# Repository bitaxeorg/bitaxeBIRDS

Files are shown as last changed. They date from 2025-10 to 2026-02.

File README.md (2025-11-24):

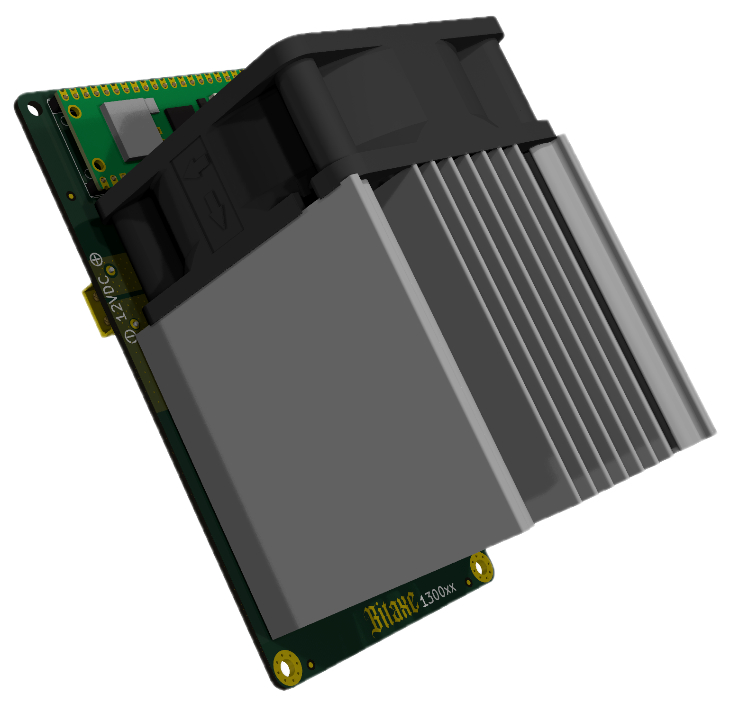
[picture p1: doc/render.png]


Bitaxe Intel Reference Design System (BIRDS) quad Intel BZM2 ASIC miner for BZM2 firmware development.

It is still an untested prototype! Don't build this expecting it to work out of the box. Do build it if you want to hack on some rad stuff.

- Open Hardware License; Real Open Source.
	- [KiCAD](https://kicad.org) design files. 
- Four Intel BZM2 ASICs, powered in series.
	- Each BZM2 is [nominally](doc/specs.md) 0.7V with approx 350 GH/s @ 1.15 GHz hash frequency.
	- On chip digital temperature and voltage sensors
	- ntime rolling
	- decent cross-domain level shifting, that _hopefully_ works. 
- 11-13V XT30 input voltage
- TPS546D24S single-phase voltage regulator tuned for 2.8V output @ 20A
	- The voltage regulator backside power plane is exposed to hopefully thermally bond it with the main heatsink. 
- New fan control strategy (no more EMC2101)
- Controlled by the [RaspberryPi Pico 2W](https://www.raspberrypi.com/products/raspberry-pi-pico-2/) featuring the RP2350 microcontroller and a Infineon CYW43439 WiFi SoC
	- Rumored to have good embedded Rust support
	- Programmable IO controller for integrating with the gnarly 5Mbaud, 9bit serial on the BZM2
    - Preliminary support with the [bitaxe-raw-pico](https://github.com/bitaxeorg/bitaxe-raw/tree/pico) firmware.
    	- Note: this targets the RP2040 in the Pico. It's pin compatible with with RP2350-based Pico 2. 
- Gerbers _not_ provided to discourage side hacks and AliEx slop. HMU if you need help generating gerbers with KiCad.

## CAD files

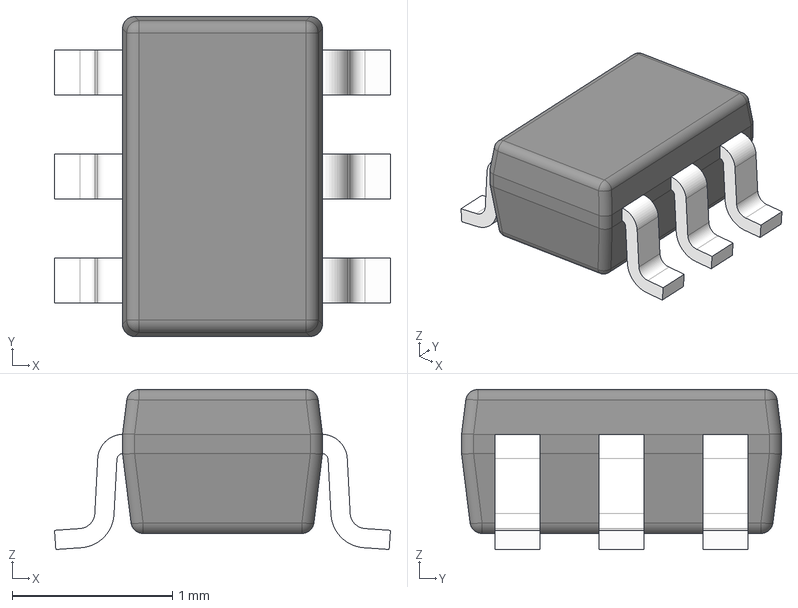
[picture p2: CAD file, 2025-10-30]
3d/DCK0006A.stp
2.10 x 2.00 x 1.00 mm
BODY-SOT
LEAD-SOT x 6
PIN1-ID

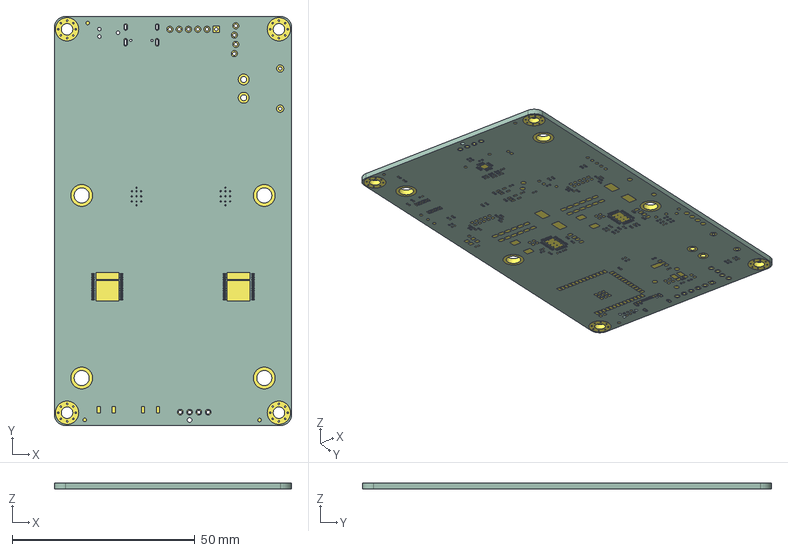
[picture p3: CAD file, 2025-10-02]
bitaxeBIRDS.step
65.0 x 112.0 x 1.59 mm
BitaxeGT_pad
BitaxeGT_PCB

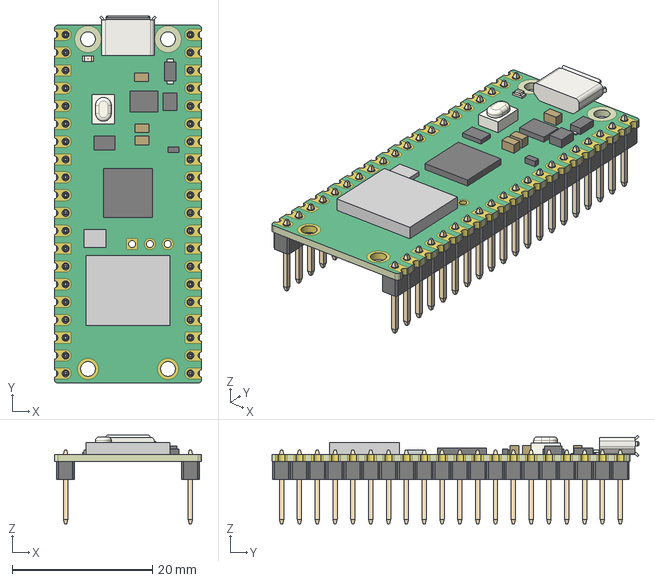
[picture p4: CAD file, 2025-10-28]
3d/RaspberryPi_Pico_W_AddedHeaders.step
21.0 x 52.3 x 12.6 mm

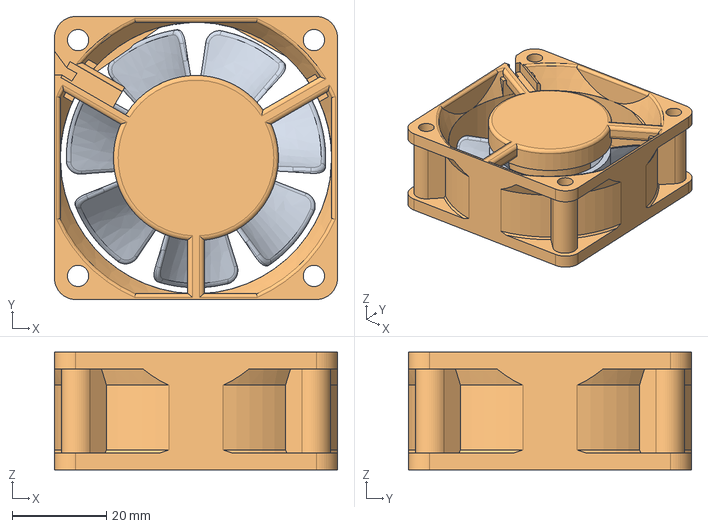
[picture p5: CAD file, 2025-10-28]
3d/Fan 60x60x25mm.stp
60.0 x 60.0 x 25.0 mm

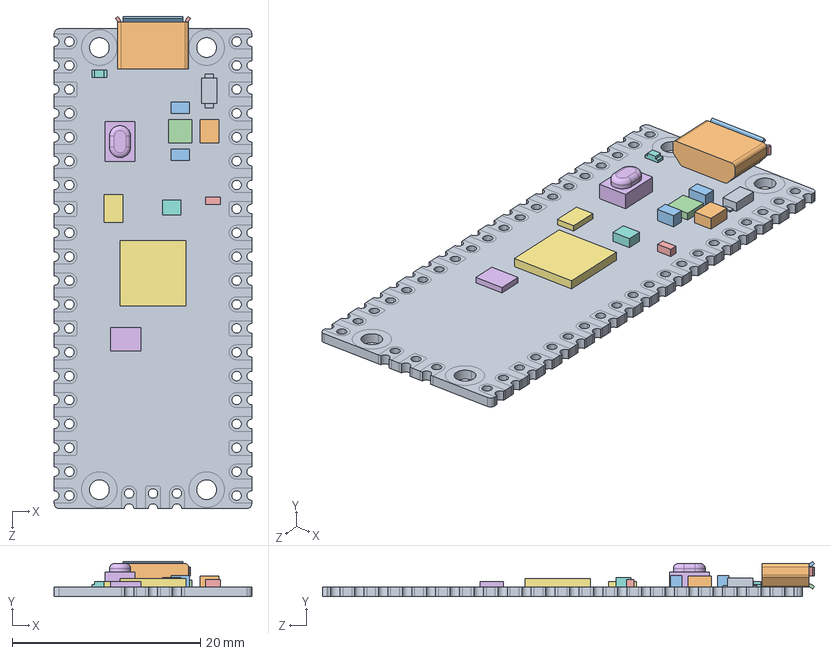
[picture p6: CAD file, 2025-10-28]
3d/RP-006426-DD-A-Raspberry Pi Pico 2 3D CAD Model R5 24 07 24.step
21.0 x 3.73 x 52.3 mm
PICO_REF_BOARD
PICO_REF_USB
PICO_REF_SWITCH
PICO_REF_MICROCONTROLLER
PICO_REF_LED
PICO_REF_COMP_1
PICO_REF_COMP_2
PICO_REF_COMP_3 x 2
PICO_REF_COMP_4
PICO_REF_COMP_5
PICO_REF_COMP_6
PICO_REF_COMP_7
PICO_REF_INDUCTOR

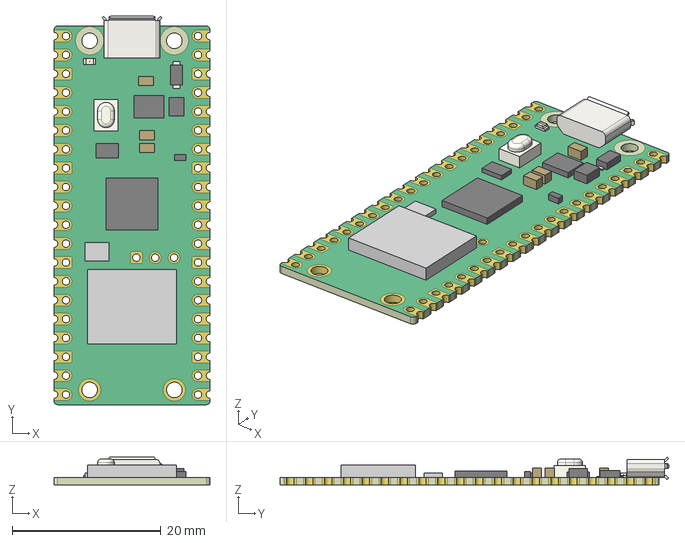
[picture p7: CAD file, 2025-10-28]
3d/RaspberryPi_Pico_W.step
21.0 x 52.3 x 3.75 mm

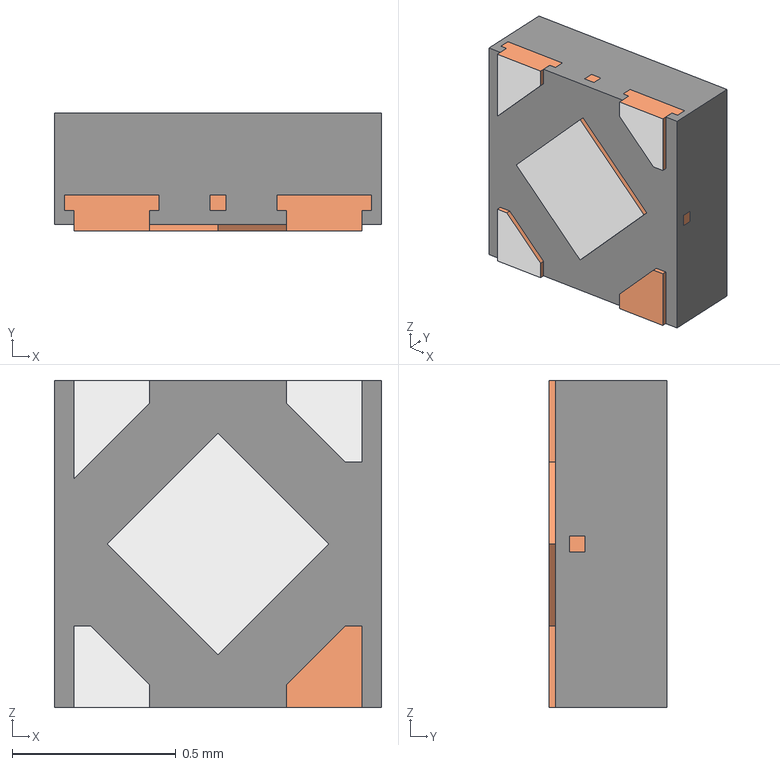
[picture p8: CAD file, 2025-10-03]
3d/DQN0004A.stp
1.00 x 0.36 x 1.00 mm
MOLD-SNB04A
FRAME-SNB04A

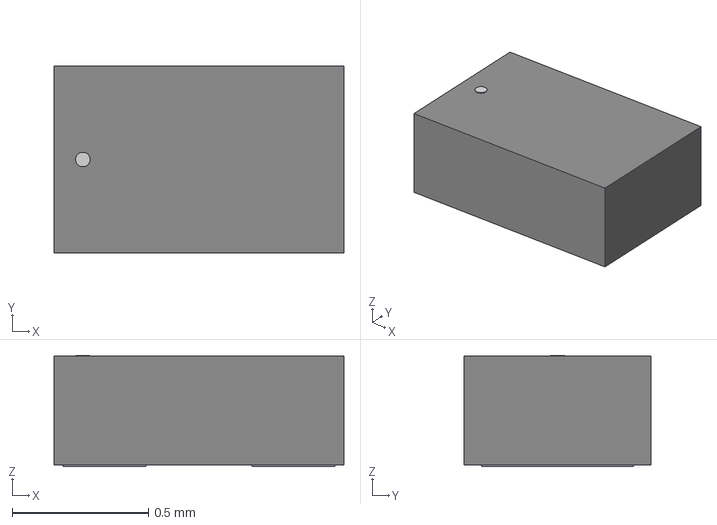
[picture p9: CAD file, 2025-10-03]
3d/DIODE_DLLFSD01LPH4-7B_DIO.step
1.07 x 0.686 x 0.409 mm

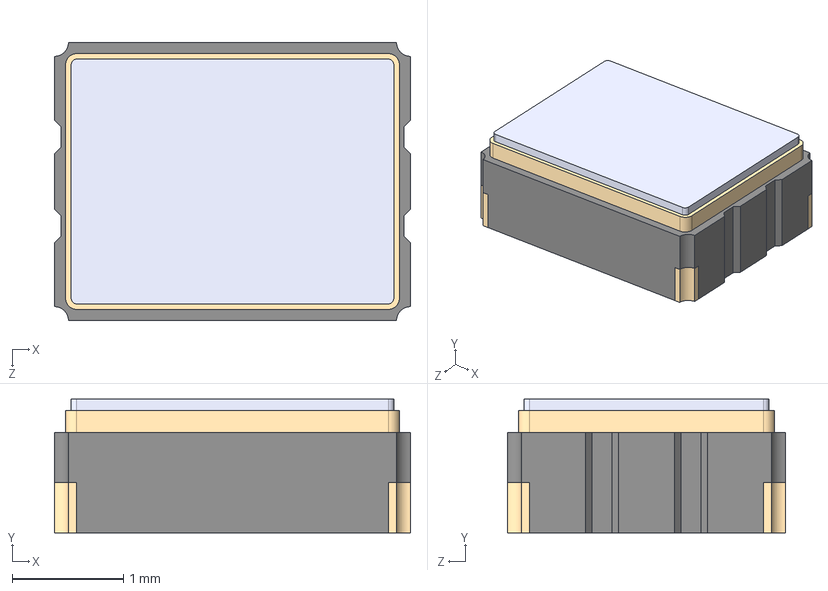
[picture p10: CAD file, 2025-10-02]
3d/ECS-3225MV-500-CN-TR.STEP
3.20 x 1.20 x 2.50 mm

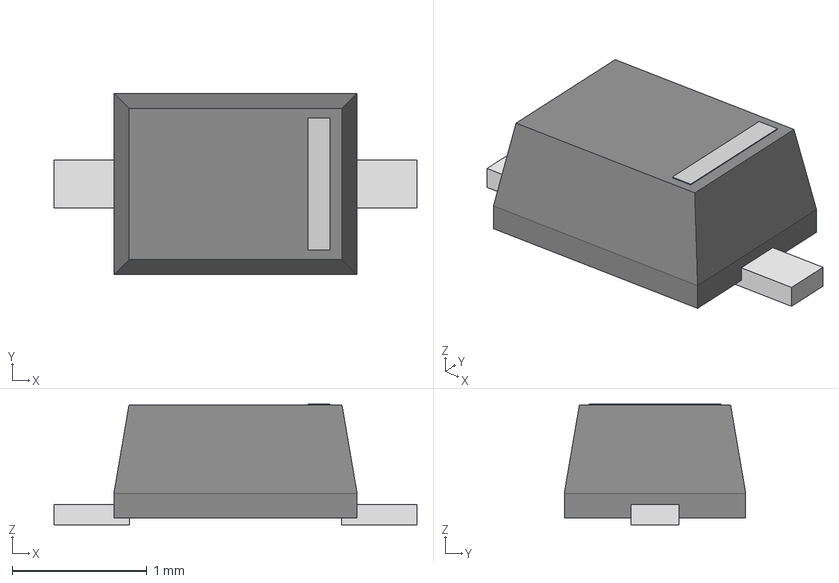
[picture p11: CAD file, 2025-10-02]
3d/SOD-323FL_UMD2__ROM.step
2.69 x 1.35 x 0.895 mm

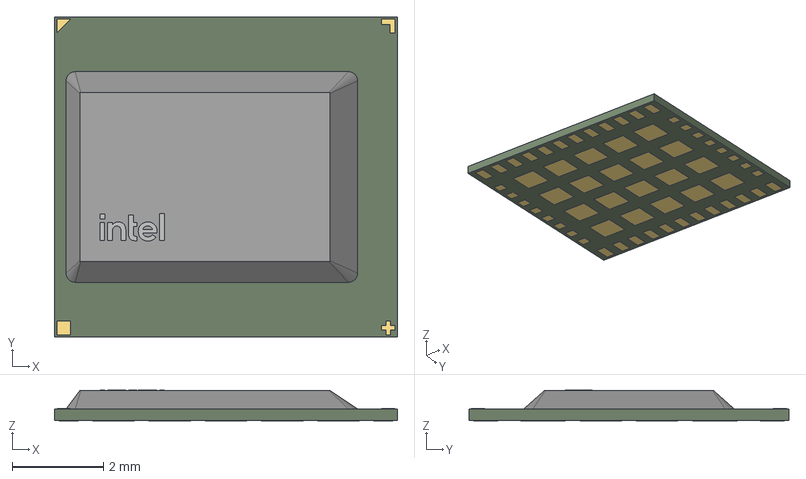
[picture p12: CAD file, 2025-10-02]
3d/BZM2.step
7.50 x 7.00 x 0.669 mm
substrate_part
die_part
underfill_part
intelLogo_part
pin1_part
square_part
plus_part
bracket_part
pads_part

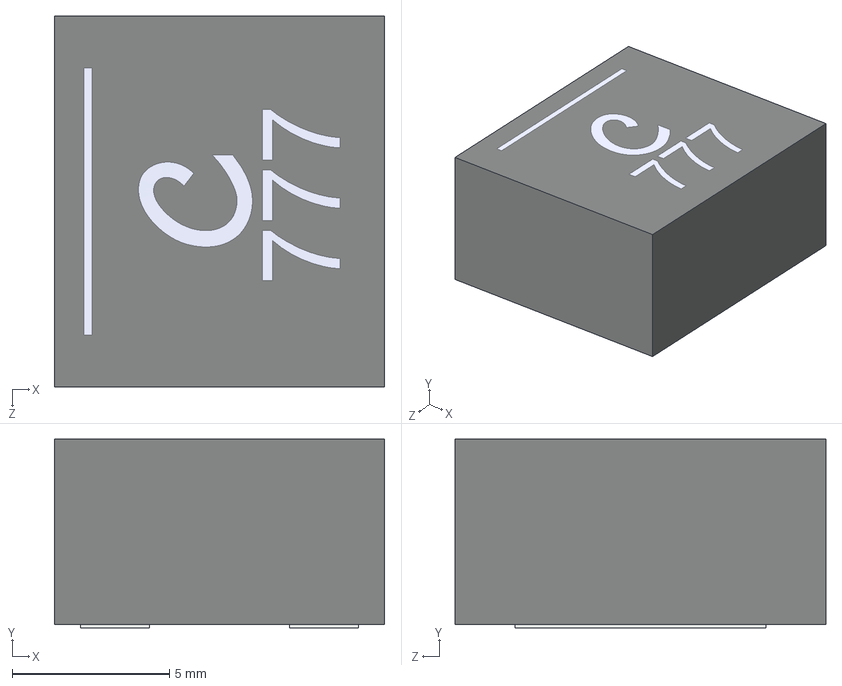
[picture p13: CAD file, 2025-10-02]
3d/Coilcraft-XAL1060.STEP
10.5 x 6.00 x 11.8 mm

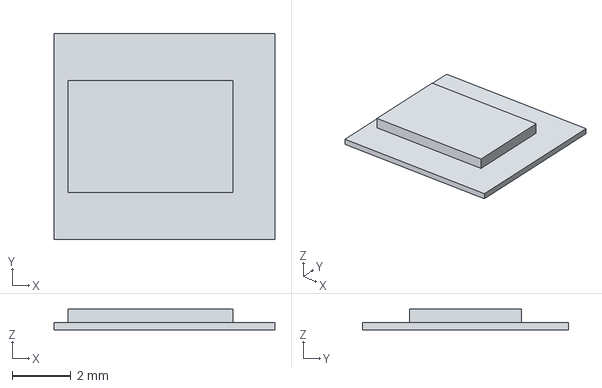
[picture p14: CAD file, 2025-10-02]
3d/BZM2model.step
7.50 x 7.00 x 0.71 mm

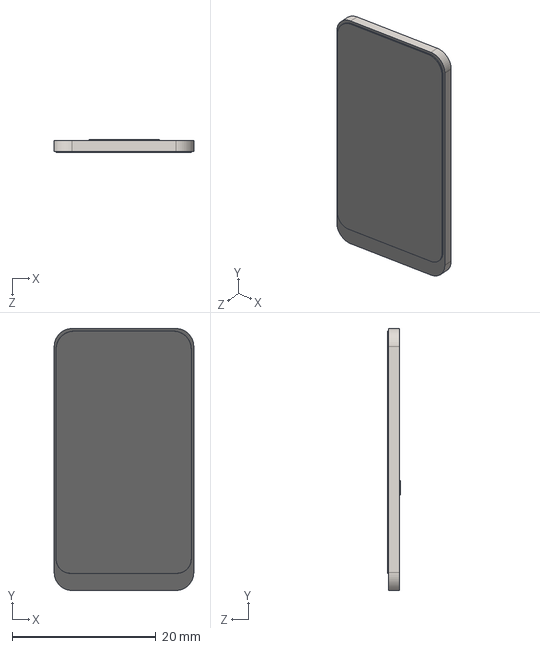
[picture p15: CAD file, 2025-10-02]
3d/DISST7789-176x320.STEP
19.4 x 36.4 x 1.86 mm

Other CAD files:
3d/TXB0104RGYR.STEP
3d/ESP32-S3-WROOM-1-N8R2--3DModel-STEP-56544.STEP
3d/TPS546D24ARVFR.step
3d/BitaxeGT_heatsink.step
3d/141_TL3330AFxxxQG.stp
3d/21-0164B_L622-1_MXM.step
3d/2R5TPE220MAFB.step
3d/470531000.stp
3d/54-00164.STEP
3d/BM04B-SRSS-TB.STEP
3d/BM1368xx.stp
3d/BQB0016A.stp
3d/Bitaxe_Heatsink.step
3d/CS1213AG-tr.stp
3d/CUI_DEVICES_PJ-002AH.step
3d/CUI_DEVICES_PJ-036AH-SMT-TR.step
3d/CUI_DEVICES_PJ-037AH.step
3d/CX3225SB16000H0FLJCC.STEP
3d/Coilcraft-SLC1175.STEP
3d/Cree_PLCC6.stp
3d/DHVQFN14_SOT762-1_NEX.step
3d/DQG0008A.stp
3d/DQH0008A.stp
3d/DRC0010J.stp
3d/DRL0006A.stp
3d/FFC2B35-08-T.STEP
3d/FP1006V2-R.STEP
3d/FPC-SMD_P0.50-8P_FGS-XJ-H2.0.step
3d/FTSH-105-01-F-DV-K.stp
3d/GT heatsink.step
3d/IHLP2020CZ.step
3d/IND_-1R5MC_SUM.step
3d/OLED_0.91_128x32.stp
3d/PLCC6_LED_3_5X3_4X2_8_CRW.step
3d/QFN16_4X4_MCH.step
3d/SLC1175-271MEC_COC.step
3d/SMV_z90.stp
3d/SN74AXC1T45DBVR.STEP
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

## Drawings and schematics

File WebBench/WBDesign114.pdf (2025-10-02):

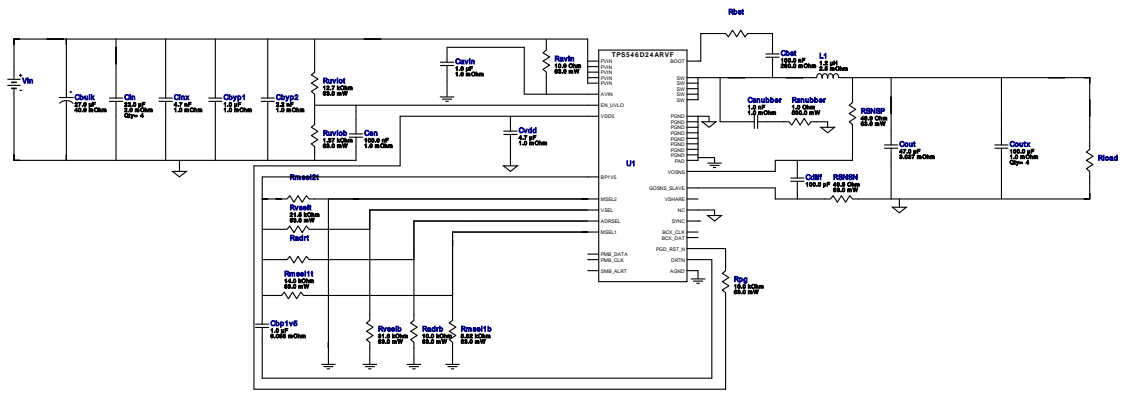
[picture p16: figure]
Cbyp2 2.2 nF 1.0 m Ohm; Cen 100.0 nF 1.0 m Ohm; Rsnubber 1.0 Ohm; Ruvlob 1.37 kOhm 63.0 m W; Cdiff 100.0 pF; Cavin 1.0 µF 1.0 m Ohm Ruvlot 12.7 kOhm; Coutx 100.0 µF 1.0 m Ohm Qty= 4; Cin 22.0 µF 2.0 m Ohm Qty= 4; RSNSN 49.9 Ohm 63.0 m W; Cout 47.0 µF; 3.037 m Ohm; RSNSP 49.9 Ohm 63.0 m W; Cinx 4.7 nF 1.0 m Ohm; Cbp1v5 1.0 µF 6.065 m Ohm; Cbyp1 1.0 µF 1.0 m Ohm; Rvselb 31.6 kOhm 63.0 m W; Rbst; Rpg 10.0 kOhm 63.0 m W; Ravin 10.0 Ohm 63.0 m W; Radrt; Rm sel2t; Rvselt 21.5 kOhm; L1 1.2 µH 2.5 m Ohm; Csnubber 1.0 nF; 1.0 m Ohm; Cbulk 27.0 µF 40.0 m Ohm; Cvdd 4.7 µF 1.0 m Ohm; Rm sel1t 14.0 kOhm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

Copyright © 2025, Texas Instruments Incorporated | 1 | ti.com/webench

WEBENCH®
Design Report TPS546D24ARVFR : TPS546D24ARVFR 11V-13V to 2.80V @ 20A October 2, 2025 14:52:55 GMT-05:00

## WEBENCH ® Design Report

Design : 114 TPS546D24ARVFR
TPS546D24ARVFR 11V-13V to 2.80V @ 20A

VinMin = 11.0V
VinMax = 13.0V
Vout = 2.8V
Vout Sch = 2.8V
Iout = 20.0A

Device = TPS546D24ARVFR
Topology = Buck
Created = 2025-09-15 13:40:46.376 BOM Cost = $8.70
BOM Count = 34
Total Pd = 3.45W
1. Do not place Rmsel2t, Radrt resistors. Place 0 Ohm resistor for Rbst.

### Design Alerts

Component Selection Information
DESIGN ERROR MESSAGE: For the entered input condition Phase margin is 44 ( less than 45 degree), try changing the compensation gains to match the recommended VLOOP and ILOOP in the OPERATING VALUES Compensation tab. Try to increase switching frequency or reduce inductance. The TPS546D24A is a PMBus(TM) device with key features listed below: PMBus(TM) features marked with * are included in WEBENCH(R) Power Designer. - Adaptive Voltage Scaling (AVS) through VOUT_COMMAND*, - Output voltage and current monitoring,
- Thermal Shutdown, - Programmable over current protection, - OCP,OV, UV, OT Levels, - Selectable Internal Compensation*, - Selectable Switching Frequency*, - Turn-On and Turn-Off Delays, - UVLO*, Soft-Start*,OCP* and Soft-Stop. Use the Advanced Options on the left side to set the PMBus(TM) commands. Please refer to the TPS546D24A datasheet and visit http://www.ti.com/pmbus for more information.

## Electrical BOM

Name | Manufacturer | Part Number | Properties | Qty Price | Footprint
Cavin | Taiyo Yuden | TMK212BJ105KG-T Series= X5R | Cap= 1.0 uF ESR= 1.0 mOhm VDC= 25.0 V IRMS= 0.0 A
1 | $0.03
| | | | | 0805 7 mm²
Cbp1v5 | MuRata | GRM188R60J105KA01D (http://psearch.en.murata.com/capacitor/result/smd/?status%3Dall%26pid%3DGRM188R60J105KA01D) Series= X5R

Cap= 1.0 uF
ESR= 6.065 mOhm
VDC= 6.3 V
IRMS= 1.36934 A

1 $0.01
0603 5 mm²
Cbst | AVX | 08053C104KAT2A (http://datasheets.avx.com/X7RDielectric.pdf) Series= X7R

Cap= 100.0 nF
ESR= 280.0 mOhm
VDC= 25.0 V
IRMS= 0.0 A

1 $0.01
0805 7 mm²

Design

Copyright © 2025, Texas Instruments Incorporated | 2 | ti.com/webench
Name | Manufacturer | Part Number | Properties | Qty Price | Footprint
Cbulk | Panasonic | 25SVPF27MX Series= SVPF | Cap= 27.0 uF ESR= 40.0 mOhm VDC= 25.0 V IRMS= 2.45 A
1 | $0.47
| | | | | CAPSMT_62_E61 53 mm²
Cbyp1 | Taiyo Yuden | TMK212BJ105KG-T Series= X5R | Cap= 1.0 uF ESR= 1.0 mOhm VDC= 25.0 V IRMS= 0.0 A
1 | $0.03
| | | | | 0805 7 mm²
Cbyp2 | MuRata | GRM155R61E222KA01D (http://search.murata.co.jp/Ceramy/PnsearchViewAction.do) Series= X5R

Cap= 2.2 nF
ESR= 1.0 mOhm
VDC= 25.0 V
IRMS= 0.0 A

1 $0.01
0402 3 mm²
Cdiff | Kemet | C0201C101K3GACTU (http://www.kemet.com/docfinder?Partnumber%3DC0201C101K3GACTU) Series= C0G/NP0

Cap= 100.0 pF
VDC= 10.0 V
IRMS= 0.0 A

1 $0.01
0201 2 mm²
Cen | MuRata | GRM155R71A104KA01D (http://search.murata.co.jp/Ceramy/PnsearchViewAction.do) Series= X7R

Cap= 100.0 nF
ESR= 1.0 mOhm
VDC= 10.0 V
IRMS= 0.0 A

1 $0.01
0402 3 mm²
Cin | MuRata | GRM32ER61E226KE15L (http://search.murata.co.jp/Ceramy/image/img/A01X/G101/ENG/GRM32ER61E226KE15%2D01.pdf) Series= X5R

Cap= 22.0 uF
ESR= 2.0 mOhm
VDC= 25.0 V
IRMS= 3.67 A

4 $0.23
1210 15 mm²
Cinx | MuRata | GRM155R71E472KA01D (http://search.murata.co.jp/Ceramy/PnsearchViewAction.do) Series= X7R

Cap= 4.7 nF
ESR= 1.0 mOhm
VDC= 25.0 V
IRMS= 0.0 A

1 $0.01
0402 3 mm²
Cout | MuRata | GRM32ER61C476KE15L (http://psearch.en.murata.com/capacitor/result/smd/?status%3Dall%26pid%3DGRM32ER61C476KE15L) Series= X5R

Cap= 47.0 uF
ESR= 3.037 mOhm
VDC= 16.0 V
IRMS= 4.59346 A

1 $0.17
1210_280 15 mm²
Coutx | MuRata | GRM32EC80J107ME20L Series= X6S

Cap= 100.0 uF
ESR= 1.0 mOhm
VDC= 6.3 V
IRMS= 6.0 A
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

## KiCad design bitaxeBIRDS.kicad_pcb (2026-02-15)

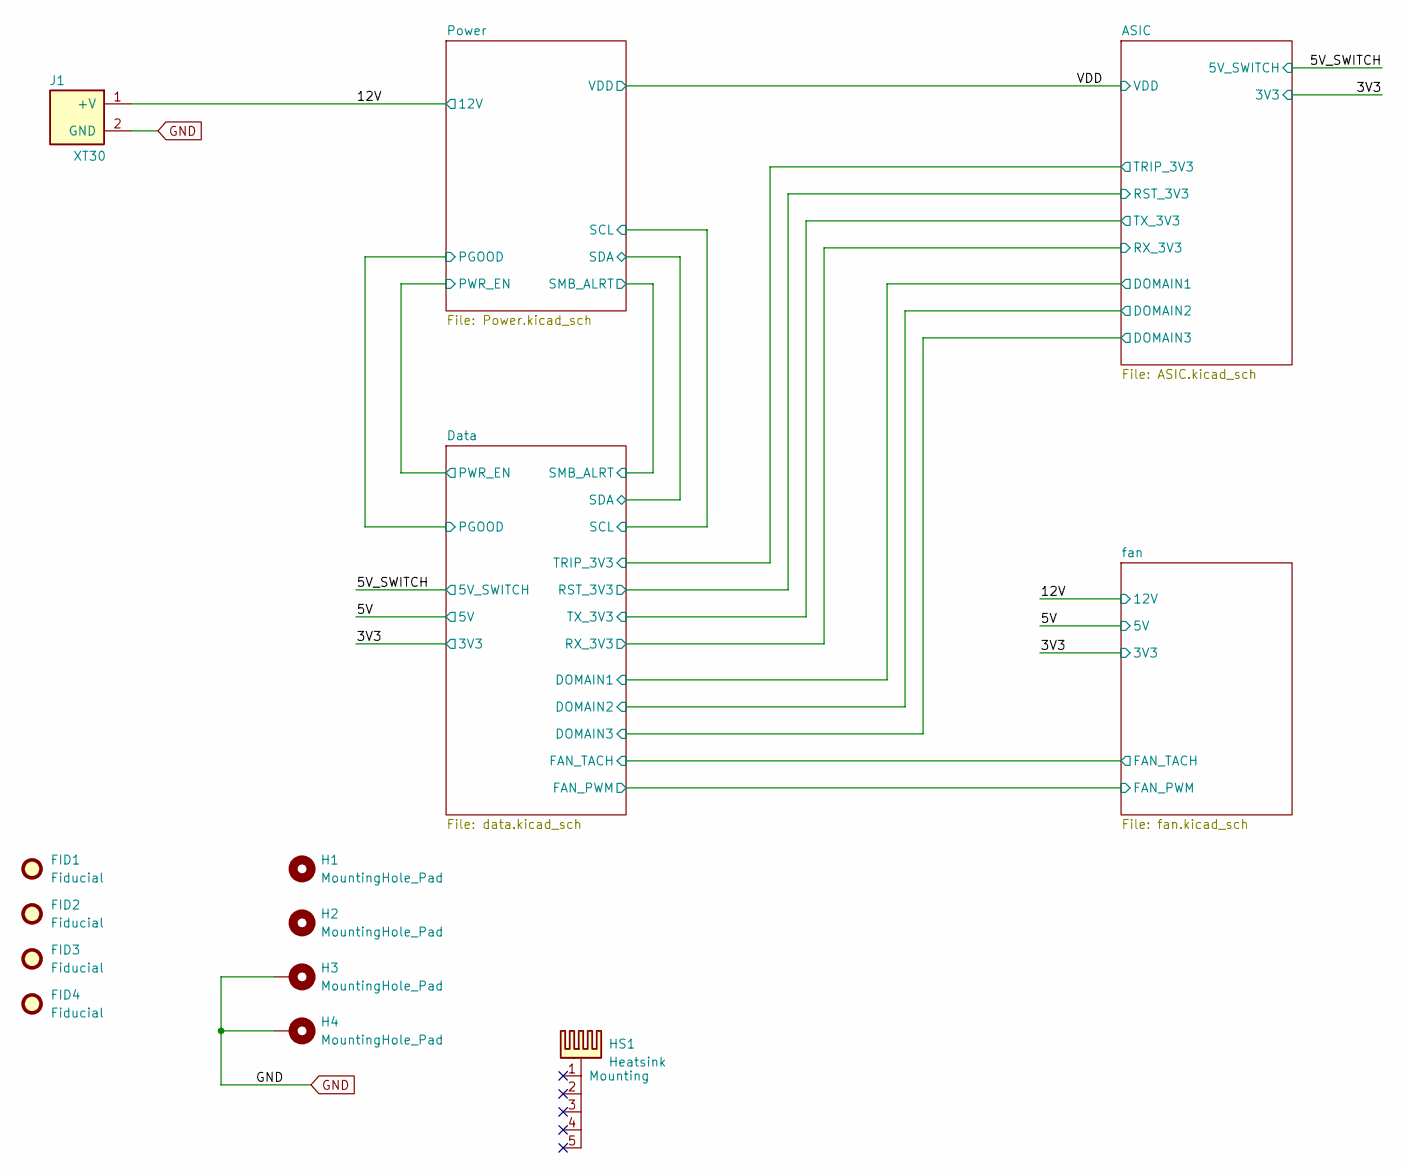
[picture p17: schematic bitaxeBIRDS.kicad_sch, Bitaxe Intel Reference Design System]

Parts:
FID1, FID2, FID3, FID4: Fiducial; Fiducial_1mm_Mask2mm
H1, H2: MountingHole_Pad; MountingHole_3.2mm_M3
H3, H4: MountingHole_Pad; MountingHole_3.2mm_M3_Pad_Via
HS1: Heatsink; Heatsink-5hole-BitaxeGT
J1: XT30; XT30PW-M; PARTNO XT30PW-M; LCSC C431092

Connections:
/12V: J1.1 (+V); also elsewhere on the board
GND: H3.1, H4.1, J1.2 (GND); also elsewhere on the board

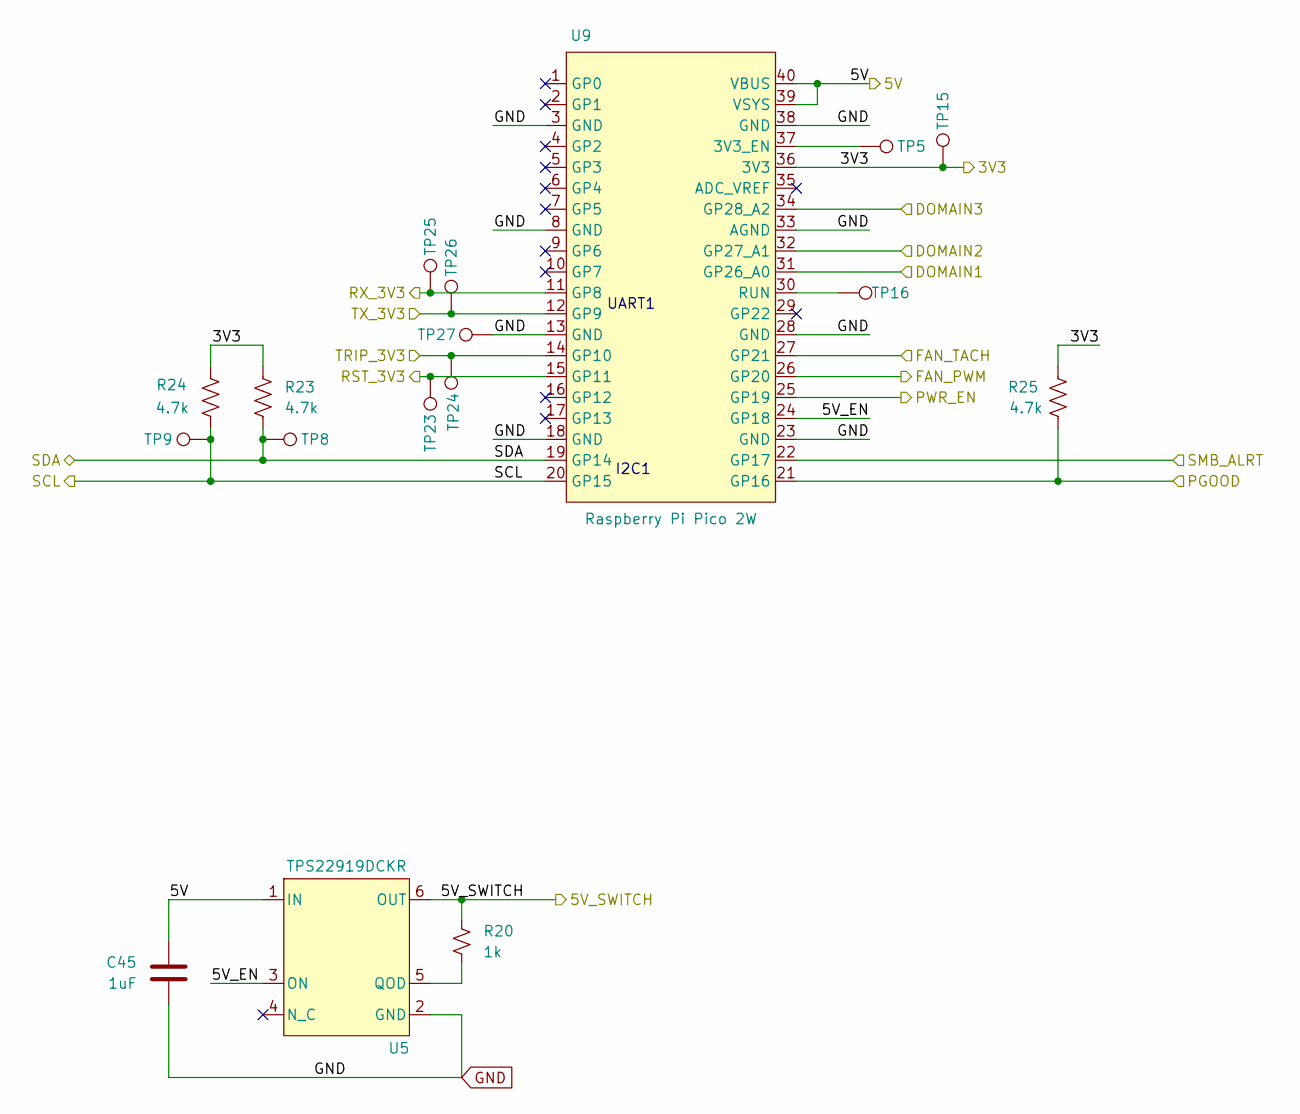
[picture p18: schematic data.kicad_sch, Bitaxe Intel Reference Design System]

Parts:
C45: 1uF; C_0402_1005Metric; PARTNO EMK105BJ105MV-F
R20: 1k; R_0402_1005Metric; PARTNO RC0402FR-071KL
R23, R24, R25: 4.7k; R_0402_1005Metric; PARTNO RC0402FR-074K7L
TP5: 3V3 EN; TestPoint_Pad_D1.0mm
TP8: SDA; TestPoint_Pad_D1.0mm
TP9: SCL; TestPoint_Pad_D1.0mm
TP15: 3V3; TestPoint_Pad_D1.0mm
TP16: RUN; TestPoint_Pad_D1.0mm
TP23: RST; TestPoint_Pad_D1.0mm
TP24: TT; TestPoint_Pad_D1.0mm
TP25: RX; TestPoint_Pad_D1.0mm
TP26: TX; TestPoint_Pad_D1.0mm
TP27: GND; TestPoint_Pad_D1.0mm
U5: TPS22919DCKR; DCK0006A_N; PARTNO TPS22919DCKR
U9: Raspberry Pi Pico 2W; RaspberryPi_Pico_Common_THT

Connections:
/3V3: R23.1, R24.2, R25.2, TP15.1, U9.36 (3V3); also elsewhere on the board
/5V: C45.1, U5.1 (IN), U9.39 (VSYS), U9.40 (VBUS); also elsewhere on the board
/5V_SWITCH: R20.1, U5.6 (OUT); also elsewhere on the board
/ASIC/GND2: U9.31 (GP26_A0); also elsewhere on the board
/ASIC/GND3: U9.32 (GP27_A1); also elsewhere on the board
/ASIC/GND4: U9.34 (GP28_A2); also elsewhere on the board
/ASIC/RST_3V3: TP23.1, U9.15 (GP11); also elsewhere on the board
/ASIC/RX_3V3: TP25.1, U9.11 (GP8); also elsewhere on the board
/ASIC/TRIP_3V3: TP24.1, U9.14 (GP10); also elsewhere on the board
/ASIC/TX_3V3: TP26.1, U9.12 (GP9); also elsewhere on the board
/Data/5V_EN: U5.3 (ON), U9.24 (GP18)
/Data/FAN_PWM: U9.26 (GP20); also elsewhere on the board
/Data/FAN_TACH: U9.27 (GP21); also elsewhere on the board
/Data/SCL: R24.1, TP9.1, U9.20 (GP15); also elsewhere on the board
/Data/SDA: R23.2, TP8.1, U9.19 (GP14); also elsewhere on the board
/Power/PGOOD: R25.1, U9.21 (GP16); also elsewhere on the board
/Power/PWR_EN: U9.25 (GP19); also elsewhere on the board
/Power/SMB_ALRT: U9.22 (GP17); also elsewhere on the board
GND: C45.2, TP27.1, U5.2 (GND), U9.3 (GND), U9.8 (GND), U9.13 (GND), U9.18 (GND), U9.23 (GND), U9.28 (GND), U9.33 (AGND), U9.38 (GND); also elsewhere on the board
unnamed: R20.2, U5.5 (QOD)
unnamed: TP5.1, U9.37 (3V3_EN)
unnamed: TP16.1, U9.30 (RUN)

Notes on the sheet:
UART1
I2C1

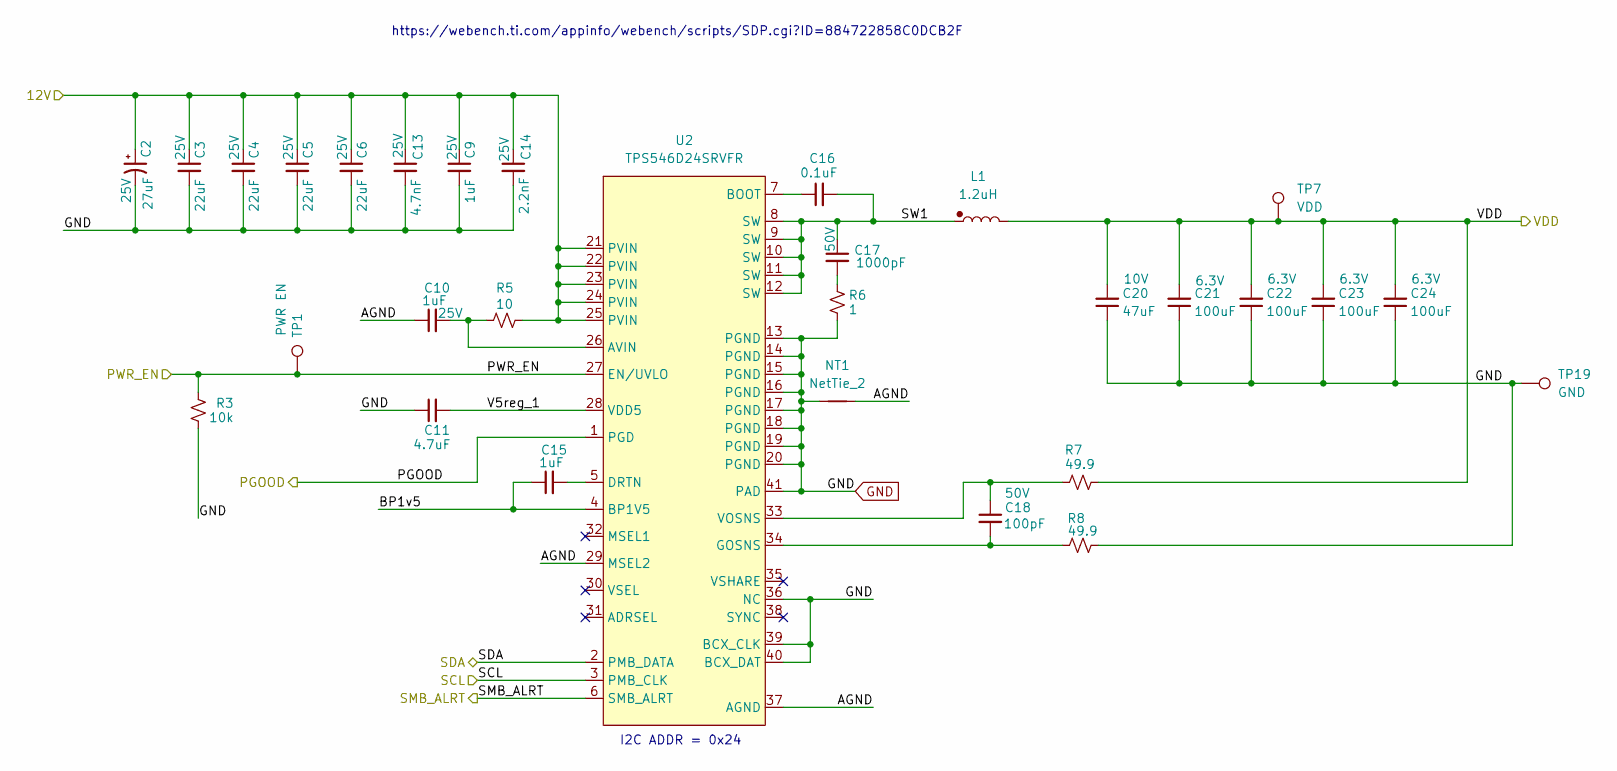
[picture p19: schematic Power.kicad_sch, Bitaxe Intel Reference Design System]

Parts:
C2: 27uF; CP_Elec_5x5.9; Voltage 25V; PARTNO APXG250ARA270MF46G
C3, C4, C5, C6: 22uF; C_1206_3216Metric; Voltage 25V; PARTNO TMK316BBJ226ML-T
C9, C10: 1uF; C_0603_1608Metric; Voltage 25V; PARTNO TMK107B7105KA-T
C11: 4.7uF; C_0402_1005Metric; PARTNO GRM155R61A475MEAAD
C13: 4.7nF; C_0402_1005Metric; Voltage 25V; PARTNO GRM155R71E472KA01D
C14: 2.2nF; C_0402_1005Metric; Voltage 25V; PARTNO GRM155R61H222KA01D
C15: 1uF; C_0402_1005Metric; PARTNO EMK105BJ105MV-F
C16: 0.1uF; C_0402_1005Metric; PARTNO KGM05AR71C104KH
C17: 1000pF; C_0805_2012Metric; Voltage 50V; PARTNO CC0805KRX7R9BB102
C18: 100pF; C_0402_1005Metric; Voltage 50V; PARTNO CC0402JRNPO9BN101
C20: 47uF; C_1206_3216Metric; Voltage 10V; PARTNO GRM31CR61A476ME15L
C21, C22, C23, C24: 100uF; C_1206_3216Metric; Voltage 6.3V; PARTNO CL31A107MQHNNNE
L1: 1.2uH; XAL1060122MEC; PARTNO XAL1060-122MEC
NT1: NetTie_2; NetTie-2_SMD_Pad0.2mmx1mm
R3: 10k; R_0402_1005Metric; PARTNO RC0402JR-0710KL
R5: 10; R_0402_1005Metric; PARTNO RC0402FR-0710RL
R6: 1; R_0805_2012Metric; PARTNO ESR10EZPJ1R0
R7, R8: 49.9; R_0402_1005Metric; PARTNO RC0402FR-0749R9L
TP1: PWR EN; TestPoint_Pad_D1.0mm
TP7: VDD; TestPoint_Pad_D1.0mm
TP19: GND; TestPoint_Pad_D1.0mm
U2: TPS546D24SRVFR; LQFN40-CLIP; PARTNO TPS546D24ARVFR

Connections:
/12V: C2.1, C3.1, C4.1, C5.1, C6.1, C9.1, C13.1, C14.1, R5.1, U2.21 (PVIN), U2.22 (PVIN), U2.23 (PVIN), U2.24 (PVIN), U2.25 (PVIN); also elsewhere on the board
/Data/SCL: U2.3 (PMB_CLK); also elsewhere on the board
/Data/SDA: U2.2 (PMB_DATA); also elsewhere on the board
/Power/AGND: C10.1, NT1.2, U2.29 (MSEL2), U2.37 (AGND)
/Power/BP1v5: C15.1, U2.4 (BP1V5)
/Power/PGOOD: U2.1 (PGD); also elsewhere on the board
/Power/PWR_EN: R3.2, TP1.1, U2.27 (EN/UVLO); also elsewhere on the board
/Power/SMB_ALRT: U2.6 (SMB_ALRT); also elsewhere on the board
/Power/SW1: C16.2, C17.1, L1.1, U2.8 (SW), U2.9 (SW), U2.10 (SW), U2.11 (SW), U2.12 (SW)
/Power/V5reg_1: C11.2, U2.28 (VDD5)
/VDD: C20.2, C21.2, C22.2, C23.2, C24.2, L1.2, R7.1, TP7.1; also elsewhere on the board
GND: C2.2, C3.2, C4.2, C5.2, C6.2, C9.2, C11.1, C13.2, C14.2, C20.1, C21.1, C22.1, C23.1, C24.1, NT1.1, R3.1, R6.2, R8.2, TP19.1, U2.13 (PGND), U2.14 (PGND), U2.15 (PGND), U2.16 (PGND), U2.17 (PGND), U2.18 (PGND), U2.19 (PGND), U2.20 (PGND), U2.36 (NC), U2.39 (BCX_CLK), U2.40 (BCX_DAT), U2.41 (PAD); also elsewhere on the board
unnamed: C17.2, R6.1
unnamed: C10.2, R5.2, U2.26 (AVIN)
unnamed: C16.1, U2.7 (BOOT)
unnamed: C15.2, U2.5 (DRTN)
unnamed: C18.2, R8.1, U2.34 (GOSNS)
unnamed: C18.1, R7.2, U2.33 (VOSNS)

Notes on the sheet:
I2C ADDR = 0x24
https://webench.ti.com/appinfo/webench/scripts/SDP.cgi?ID=884722858C0DCB2F

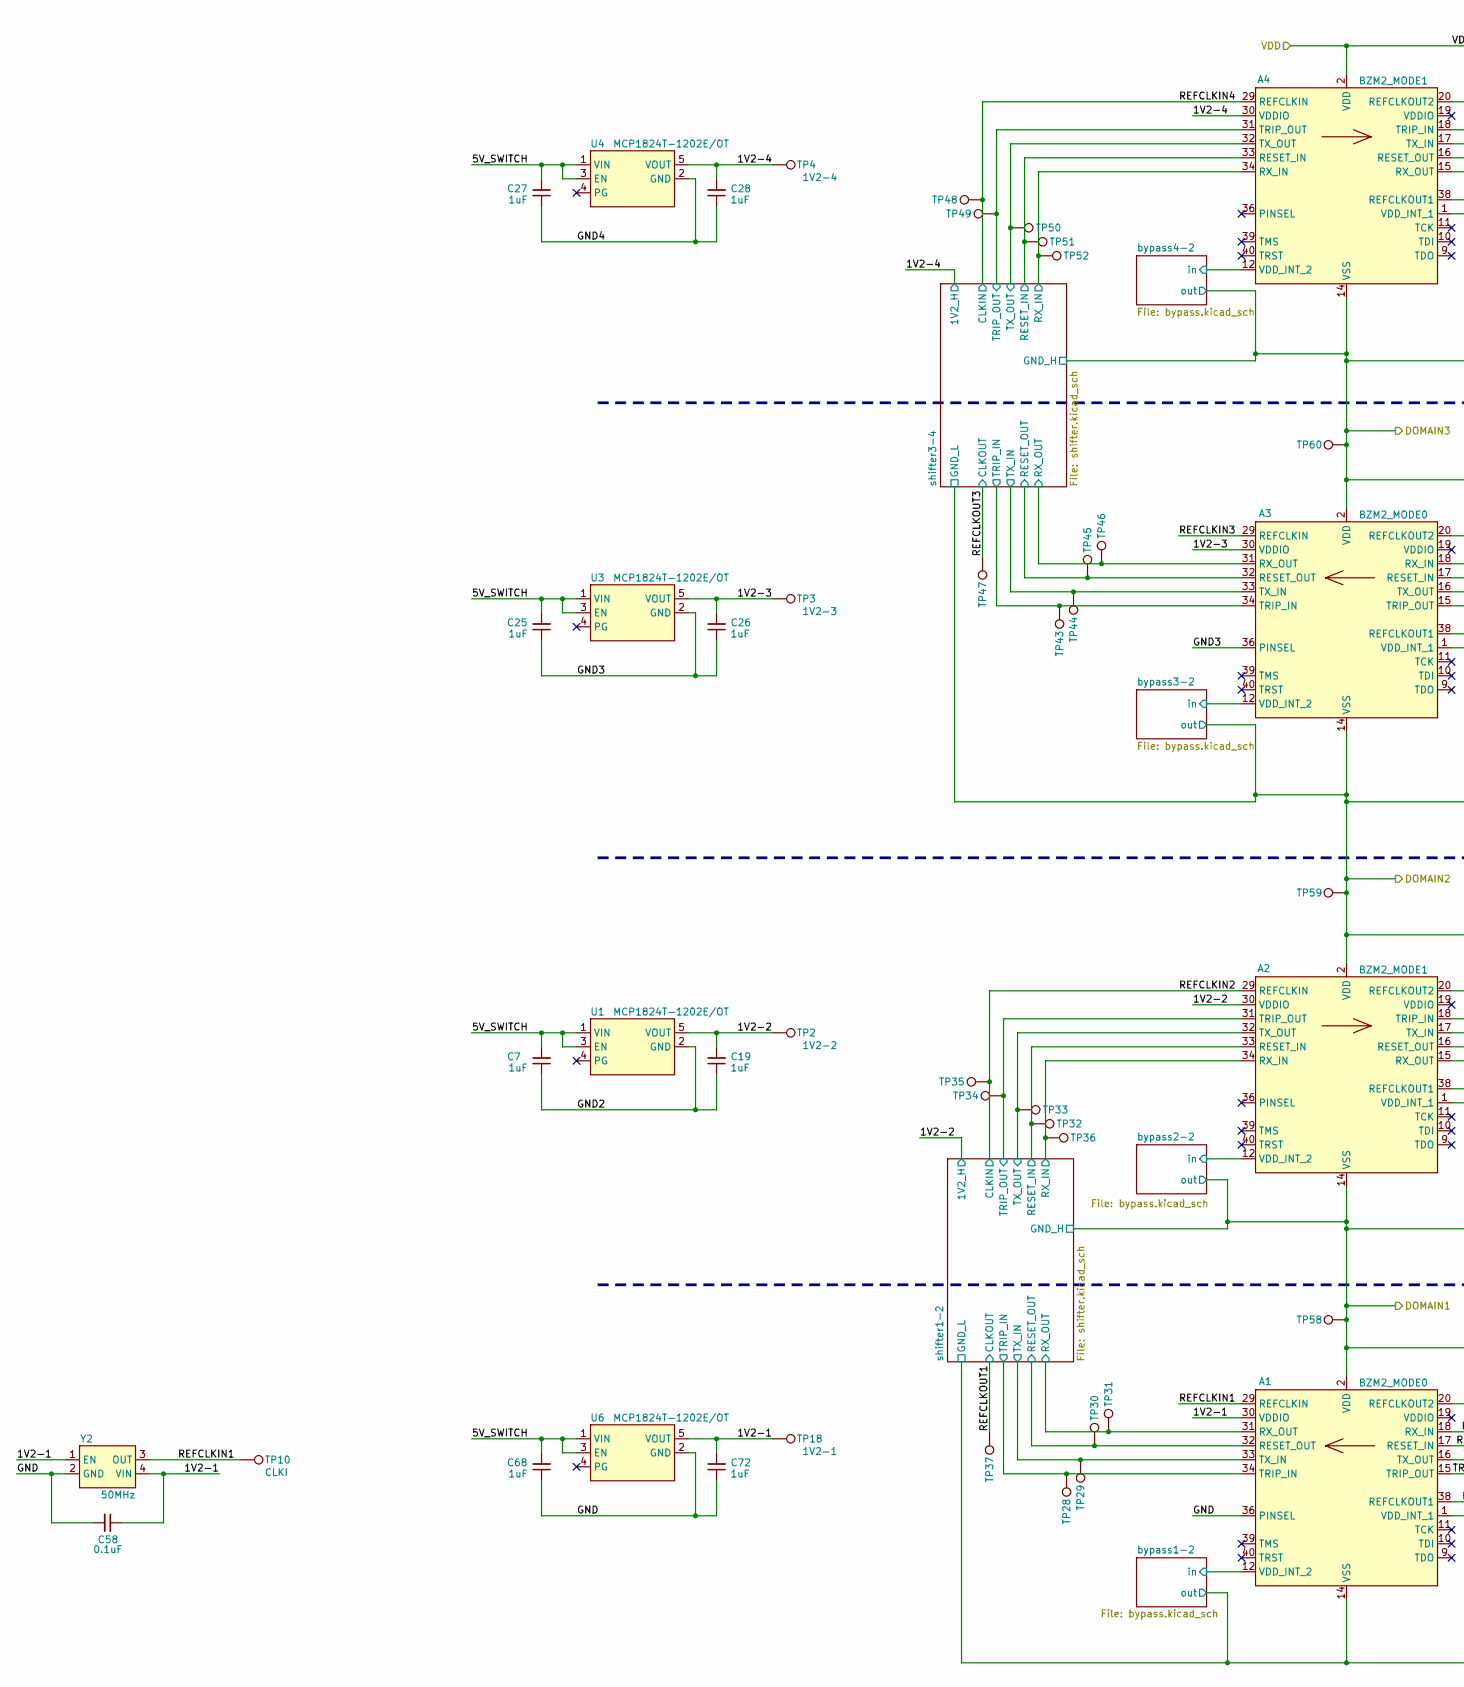
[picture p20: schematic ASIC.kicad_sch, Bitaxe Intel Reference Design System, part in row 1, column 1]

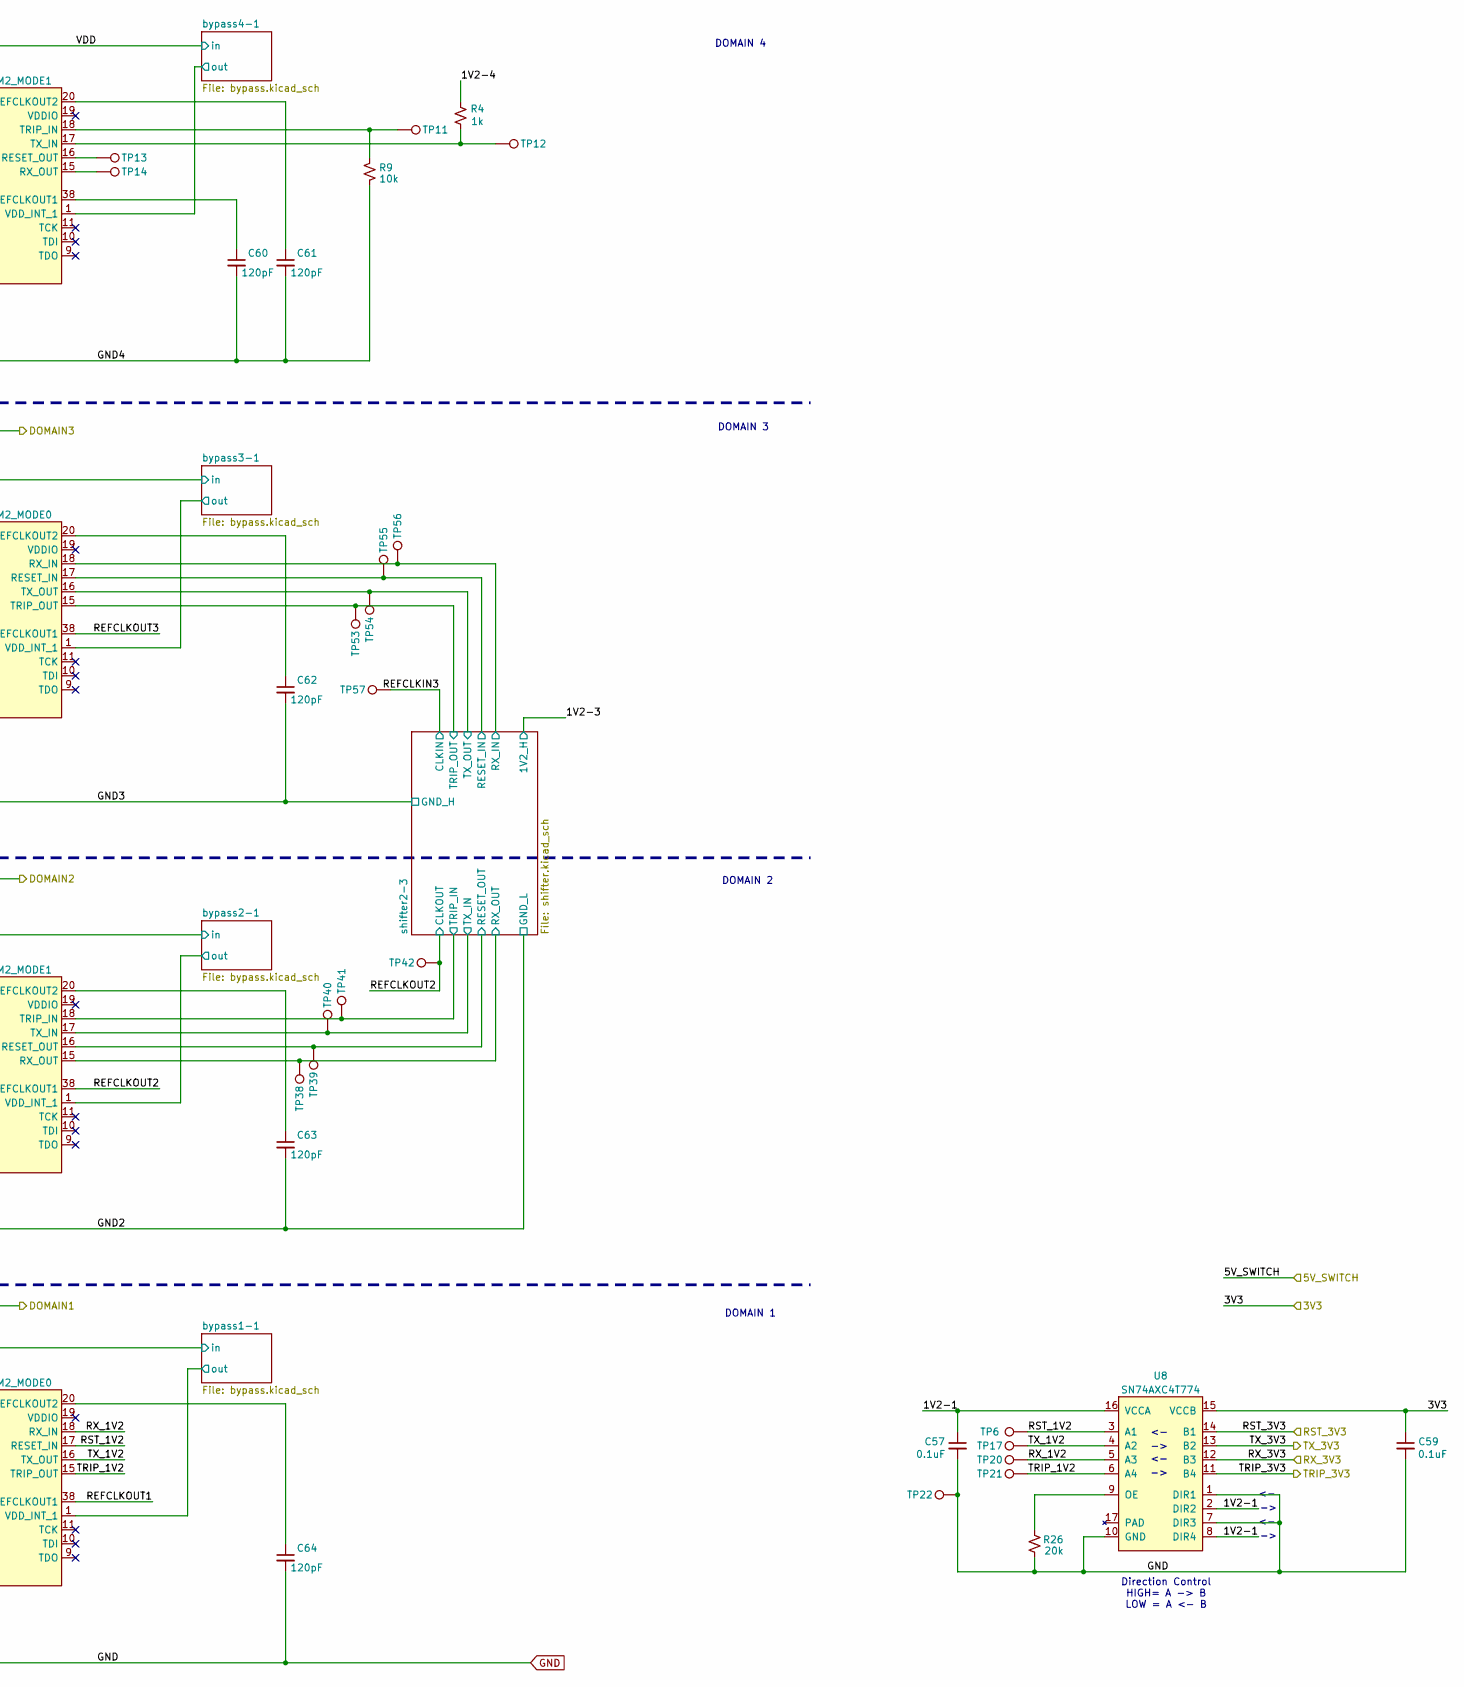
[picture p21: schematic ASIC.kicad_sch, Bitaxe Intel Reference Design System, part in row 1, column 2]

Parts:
A1, A3: BZM2_MODE0; bzm2
A2, A4: BZM2_MODE1; bzm2
C7, C19, C25, C26, C27, C28, C68, C72: 1uF; C_0402_1005Metric; PARTNO EMK105BJ105MV-F
C57, C58, C59: 0.1uF; C_0402_1005Metric; PARTNO KGM05AR71C104KH
C60, C61, C62, C63, C64: 120pF; C_0402_1005Metric; PARTNO GCM1555C1H121FA16D
R4: 1k; R_0402_1005Metric; PARTNO RC0402FR-071KL
R9: 10k; R_0402_1005Metric; PARTNO RC0402JR-0710KL
R26: 20k; R_0402_1005Metric; PARTNO RC0402FR-0720KL
TP2: 1V2-2; TestPoint_Pad_D1.0mm
TP3: 1V2-3; TestPoint_Pad_D1.0mm
TP4: 1V2-4; TestPoint_Pad_D1.0mm
TP6, TP13, TP32, TP51, TP55: RSTI; TestPoint_Pad_1.0x0.4mm
TP10: CLKI; TestPoint_Pad_D1.0mm
TP11, TP28, TP43: TTI; TestPoint_Pad_1.0x0.4mm
TP12, TP29, TP44: TXI; TestPoint_Pad_1.0x0.4mm
TP14, TP31, TP38, TP46: RXO; TestPoint_Pad_1.0x0.4mm
TP17, TP33, TP40, TP50, TP54: TXO; TestPoint_Pad_1.0x0.4mm
TP18: 1V2-1; TestPoint_Pad_D1.0mm
TP20, TP36, TP52, TP56: RXI; TestPoint_Pad_1.0x0.4mm
TP21, TP34, TP41, TP49, TP53: TTO; TestPoint_Pad_1.0x0.4mm
TP22: GND; TestPoint_Pad_1.0x0.4mm
TP30, TP39, TP45: RSTO; TestPoint_Pad_1.0x0.4mm
TP35, TP48, TP57: CLKI; TestPoint_Pad_1.0x0.4mm
TP37, TP42, TP47: CLKO; TestPoint_Pad_1.0x0.4mm
TP58: D1; TestPoint_Pad_D1.0mm
TP59: D2; TestPoint_Pad_D1.0mm
TP60: D3; TestPoint_Pad_D1.0mm
U1, U3, U4, U6: MCP1824T-1202E/OT; SOT-23-5; PARTNO MCP1824T-1202E/OT
U8: SN74AXC4T774; BQB0016A-MFG; PARTNO SN74AXC4T774BQBR
Y2: 50MHz; OSC_ECS-3225MV-500-CN-TR; PARTNO SX3M50.000E20F30THN; LCSC C5137267

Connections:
/3V3: C59.1, U8.15 (VCCB); also elsewhere on the board
/5V_SWITCH: C7.2, C25.2, C27.2, C68.2, U1.1 (VIN), U1.3 (EN), U3.1 (VIN), U3.3 (EN), U4.1 (VIN), U4.3 (EN), U6.1 (VIN), U6.3 (EN); also elsewhere on the board
/ASIC/1V2-1: A1.30 (VDDIO), C57.1, C58.1, C72.2, TP18.1, U6.5 (VOUT), U8.2 (DIR2), U8.8 (DIR4), U8.16 (VCCA), Y2.1 (EN), Y2.4 (VIN)
/ASIC/1V2-2: A2.30 (VDDIO), C19.2, TP2.1, U1.5 (VOUT); also elsewhere on the board
/ASIC/1V2-3: A3.30 (VDDIO), C26.2, TP3.1, U3.5 (VOUT); also elsewhere on the board
/ASIC/1V2-4: A4.30 (VDDIO), C28.2, R4.1, TP4.1, U4.5 (VOUT); also elsewhere on the board
/ASIC/GND2: A1.2 (VDD), A1.3 (VDD), A1.4 (VDD), A1.5 (VDD), A1.6 (VDD), A1.7 (VDD), A1.8 (VDD), A1.41 (VDD), A1.42 (VDD), A1.49 (VDD), A1.50 (VDD), A1.51 (VDD), A1.52 (VDD), A1.59 (VDD), A1.60 (VDD), A2.14 (VSS), A2.21 (VSS), A2.22 (VSS), A2.23 (VSS), A2.24 (VSS), A2.25 (VSS), A2.26 (VSS), A2.27 (VSS), A2.28 (VSS), A2.35 (VSS), A2.43 (VSS), A2.44 (VSS), A2.45 (VSS), A2.46 (VSS), A2.47 (VSS), A2.48 (VSS), A2.53 (VSS), A2.54 (VSS), A2.55 (VSS), A2.56 (VSS), A2.57 (VSS), A2.58 (VSS), C7.1, C19.1, C63.2, TP58.1, U1.2 (GND); also elsewhere on the board
/ASIC/GND3: A2.2 (VDD), A2.3 (VDD), A2.4 (VDD), A2.5 (VDD), A2.6 (VDD), A2.7 (VDD), A2.8 (VDD), A2.41 (VDD), A2.42 (VDD), A2.49 (VDD), A2.50 (VDD), A2.51 (VDD), A2.52 (VDD), A2.59 (VDD), A2.60 (VDD), A3.14 (VSS), A3.21 (VSS), A3.22 (VSS), A3.23 (VSS), A3.24 (VSS), A3.25 (VSS), A3.26 (VSS), A3.27 (VSS), A3.28 (VSS), A3.35 (VSS), A3.36 (PINSEL), A3.43 (VSS), A3.44 (VSS), A3.45 (VSS), A3.46 (VSS), A3.47 (VSS), A3.48 (VSS), A3.53 (VSS), A3.54 (VSS), A3.55 (VSS), A3.56 (VSS), A3.57 (VSS), A3.58 (VSS), C25.1, C26.1, C62.2, TP59.1, U3.2 (GND); also elsewhere on the board
/ASIC/GND4: A3.2 (VDD), A3.3 (VDD), A3.4 (VDD), A3.5 (VDD), A3.6 (VDD), A3.7 (VDD), A3.8 (VDD), A3.41 (VDD), A3.42 (VDD), A3.49 (VDD), A3.50 (VDD), A3.51 (VDD), A3.52 (VDD), A3.59 (VDD), A3.60 (VDD), A4.14 (VSS), A4.21 (VSS), A4.22 (VSS), A4.23 (VSS), A4.24 (VSS), A4.25 (VSS), A4.26 (VSS), A4.27 (VSS), A4.28 (VSS), A4.35 (VSS), A4.43 (VSS), A4.44 (VSS), A4.45 (VSS), A4.46 (VSS), A4.47 (VSS), A4.48 (VSS), A4.53 (VSS), A4.54 (VSS), A4.55 (VSS), A4.56 (VSS), A4.57 (VSS), A4.58 (VSS), C27.1, C28.1, C60.2, C61.2, R9.2, TP60.1, U4.2 (GND); also elsewhere on the board
/ASIC/REFCLKIN1: A1.29 (REFCLKIN), TP10.1, Y2.3 (OUT)
/ASIC/REFCLKIN2: A2.29 (REFCLKIN), TP35.1; also elsewhere on the board
/ASIC/REFCLKIN3: A3.29 (REFCLKIN), TP57.1; also elsewhere on the board
/ASIC/REFCLKIN4: A4.29 (REFCLKIN), TP48.1; also elsewhere on the board
/ASIC/REFCLKOUT1: A1.38 (REFCLKOUT1), TP37.1; also elsewhere on the board
/ASIC/REFCLKOUT2: A2.38 (REFCLKOUT1), TP42.1; also elsewhere on the board
/ASIC/REFCLKOUT3: A3.38 (REFCLKOUT1), TP47.1; also elsewhere on the board
/ASIC/RST_1V2: A1.17 (RESET_IN), TP6.1, U8.3 (A1)
/ASIC/RST_3V3: U8.14 (B1); also elsewhere on the board
/ASIC/RX_1V2: A1.18 (RX_IN), TP20.1, U8.5 (A3)
/ASIC/RX_3V3: U8.12 (B3); also elsewhere on the board
/ASIC/TRIP_1V2: A1.15 (TRIP_OUT), TP21.1, U8.6 (A4)
/ASIC/TRIP_3V3: U8.11 (B4); also elsewhere on the board
/ASIC/TX_1V2: A1.16 (TX_OUT), TP17.1, U8.4 (A2)
/ASIC/TX_3V3: U8.13 (B2); also elsewhere on the board
/ASIC/bypass1-1/out: A1.1 (VDD_INT_1); also elsewhere on the board
/ASIC/bypass1-2/in: A1.12 (VDD_INT_2); also elsewhere on the board
/ASIC/bypass2-1/out: A2.1 (VDD_INT_1); also elsewhere on the board
/ASIC/bypass2-2/in: A2.12 (VDD_INT_2); also elsewhere on the board
/ASIC/bypass3-1/out: A3.1 (VDD_INT_1); also elsewhere on the board
/ASIC/bypass3-2/in: A3.12 (VDD_INT_2); also elsewhere on the board
/ASIC/bypass4-1/out: A4.1 (VDD_INT_1); also elsewhere on the board
/ASIC/bypass4-2/in: A4.12 (VDD_INT_2); also elsewhere on the board
/ASIC/shifter1-2/RESET_IN: A2.33 (RESET_IN), TP32.1; also elsewhere on the board
/ASIC/shifter1-2/RESET_OUT: A1.32 (RESET_OUT), TP30.1; also elsewhere on the board
/ASIC/shifter1-2/RX_IN: A2.34 (RX_IN), TP36.1; also elsewhere on the board
/ASIC/shifter1-2/RX_OUT: A1.31 (RX_OUT), TP31.1; also elsewhere on the board
/ASIC/shifter1-2/TRIP_IN: A1.34 (TRIP_IN), TP28.1; also elsewhere on the board
/ASIC/shifter1-2/TRIP_OUT: A2.31 (TRIP_OUT), TP34.1; also elsewhere on the board
/ASIC/shifter1-2/TX_IN: A1.33 (TX_IN), TP29.1; also elsewhere on the board
/ASIC/shifter1-2/TX_OUT: A2.32 (TX_OUT), TP33.1; also elsewhere on the board
/ASIC/shifter2-3/RESET_IN: A3.17 (RESET_IN), TP55.1; also elsewhere on the board
/ASIC/shifter2-3/RESET_OUT: A2.16 (RESET_OUT), TP39.1; also elsewhere on the board
/ASIC/shifter2-3/RX_IN: A3.18 (RX_IN), TP56.1; also elsewhere on the board
/ASIC/shifter2-3/RX_OUT: A2.15 (RX_OUT), TP38.1; also elsewhere on the board
/ASIC/shifter2-3/TRIP_IN: A2.18 (TRIP_IN), TP41.1; also elsewhere on the board
/ASIC/shifter2-3/TRIP_OUT: A3.15 (TRIP_OUT), TP53.1; also elsewhere on the board
/ASIC/shifter2-3/TX_IN: A2.17 (TX_IN), TP40.1; also elsewhere on the board
/ASIC/shifter2-3/TX_OUT: A3.16 (TX_OUT), TP54.1; also elsewhere on the board
/ASIC/shifter3-4/RESET_IN: A4.33 (RESET_IN), TP51.1; also elsewhere on the board
/ASIC/shifter3-4/RESET_OUT: A3.32 (RESET_OUT), TP45.1; also elsewhere on the board
/ASIC/shifter3-4/RX_IN: A4.34 (RX_IN), TP52.1; also elsewhere on the board
/ASIC/shifter3-4/RX_OUT: A3.31 (RX_OUT), TP46.1; also elsewhere on the board
/ASIC/shifter3-4/TRIP_IN: A3.34 (TRIP_IN), TP43.1; also elsewhere on the board
/ASIC/shifter3-4/TRIP_OUT: A4.31 (TRIP_OUT), TP49.1; also elsewhere on the board
/ASIC/shifter3-4/TX_IN: A3.33 (TX_IN), TP44.1; also elsewhere on the board
/ASIC/shifter3-4/TX_OUT: A4.32 (TX_OUT), TP50.1; also elsewhere on the board
/VDD: A4.2 (VDD), A4.3 (VDD), A4.4 (VDD), A4.5 (VDD), A4.6 (VDD), A4.7 (VDD), A4.8 (VDD), A4.41 (VDD), A4.42 (VDD), A4.49 (VDD), A4.50 (VDD), A4.51 (VDD), A4.52 (VDD), A4.59 (VDD), A4.60 (VDD); also elsewhere on the board
GND: A1.14 (VSS), A1.21 (VSS), A1.22 (VSS), A1.23 (VSS), A1.24 (VSS), A1.25 (VSS), A1.26 (VSS), A1.27 (VSS), A1.28 (VSS), A1.35 (VSS), A1.36 (PINSEL), A1.43 (VSS), A1.44 (VSS), A1.45 (VSS), A1.46 (VSS), A1.47 (VSS), A1.48 (VSS), A1.53 (VSS), A1.54 (VSS), A1.55 (VSS), A1.56 (VSS), A1.57 (VSS), A1.58 (VSS), C57.2, C58.2, C59.2, C64.2, C68.1, C72.1, R26.1, TP22.1, U6.2 (GND), U8.1 (DIR1), U8.7 (DIR3), U8.10 (GND), Y2.2 (GND); also elsewhere on the board
unnamed: A1.20 (REFCLKOUT2), C64.1
unnamed: A2.20 (REFCLKOUT2), C63.1
unnamed: A3.20 (REFCLKOUT2), C62.1
unnamed: A4.38 (REFCLKOUT1), C60.1
unnamed: A4.20 (REFCLKOUT2), C61.1
unnamed: A4.16 (RESET_OUT), TP13.1
unnamed: A4.15 (RX_OUT), TP14.1
unnamed: A4.18 (TRIP_IN), R9.1, TP11.1
unnamed: A4.17 (TX_IN), R4.2, TP12.1
unnamed: R26.2, U8.9 (OE)

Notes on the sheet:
DOMAIN 3
DOMAIN 2
Direction Control HIGH= A -> B LOW = A <- B
DOMAIN 4
DOMAIN 1

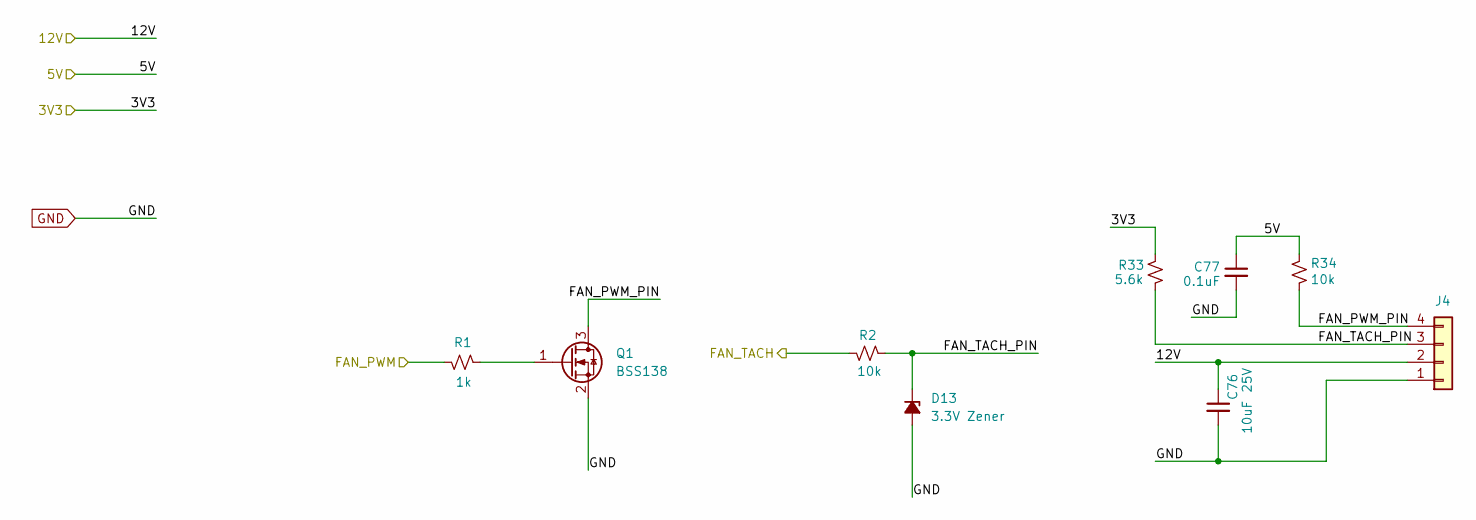
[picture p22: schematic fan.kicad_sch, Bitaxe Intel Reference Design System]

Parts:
C76: 10uF; C_0603_1608Metric; Voltage 25V; PARTNO GRM188R61E106KA73D
C77: 0.1uF; C_0402_1005Metric; PARTNO KGM05AR71C104KH
D13: 3.3V Zener; D_SOD-123; PARTNO DDZ9684-7
J4: Conn_01x04; 470531000; PARTNO 0470531000
Q1: BSS138; SOT-23; PARTNO BSS138K-13
R1: 1k; R_0402_1005Metric; PARTNO RC0402FR-071KL
R2, R34: 10k; R_0402_1005Metric; PARTNO RC0402JR-0710KL
R33: 5.6k; R_0402_1005Metric; PARTNO RC0402FR-075K6L

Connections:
/3V3: R33.2; also elsewhere on the board
/5V: C77.1, R34.2; also elsewhere on the board
/12V: C76.1, J4.2; also elsewhere on the board
/Data/FAN_PWM: R1.2; also elsewhere on the board
/Data/FAN_TACH: R2.2; also elsewhere on the board
/fan/FAN_PWM_PIN: J4.4, Q1.3 (D), R34.1
/fan/FAN_TACH_PIN: D13.1 (K), J4.3, R2.1, R33.1
GND: C76.2, C77.2, D13.2 (A), J4.1, Q1.2 (S); also elsewhere on the board
unnamed: Q1.1 (G), R1.1

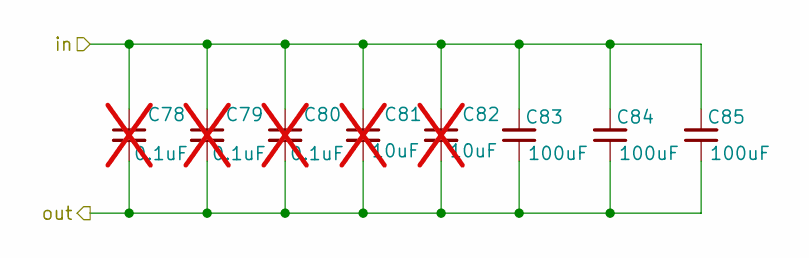
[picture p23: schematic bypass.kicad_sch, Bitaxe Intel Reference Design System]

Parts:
C78, C79, C80: 0.1uF; C_0402_1005Metric; PARTNO 0402X104K100CT; not fitted
C81, C82: 10uF; C_0603_1608Metric; PARTNO GRM188R61E106KA73D; not fitted
C83, C84, C85: 100uF; C_0805_2012Metric; voltage 4V; PARTNO GRM21BR60G107ME11K

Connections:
/ASIC/GND2: C83.2, C84.2, C85.2; also elsewhere on the board
/ASIC/bypass1-1/out: C83.1, C84.1, C85.1; also elsewhere on the board

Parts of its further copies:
C91, C92, C93, C99, C100, C101, C107, C108, C109, C115, C116, C117, C123, C124, C125, C131, C132, C133, C139, C140, C141: 100uF; C_0805_2012Metric; voltage 4V; PARTNO GRM21BR60G107ME11K

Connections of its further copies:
/ASIC/GND2: C107.1, C108.1, C109.1; also elsewhere on the board
/ASIC/GND3: C99.2, C100.2, C101.2, C123.1, C124.1, C125.1; also elsewhere on the board
/ASIC/GND4: C115.2, C116.2, C117.2, C139.1, C140.1, C141.1; also elsewhere on the board
/ASIC/bypass1-2/in: C91.2, C92.2, C93.2; also elsewhere on the board
/ASIC/bypass2-1/out: C99.1, C100.1, C101.1; also elsewhere on the board
/ASIC/bypass2-2/in: C107.2, C108.2, C109.2; also elsewhere on the board
/ASIC/bypass3-1/out: C115.1, C116.1, C117.1; also elsewhere on the board
/ASIC/bypass3-2/in: C123.2, C124.2, C125.2; also elsewhere on the board
/ASIC/bypass4-1/out: C131.1, C132.1, C133.1; also elsewhere on the board
/ASIC/bypass4-2/in: C139.2, C140.2, C141.2; also elsewhere on the board
/VDD: C131.2, C132.2, C133.2; also elsewhere on the board
GND: C91.1, C92.1, C93.1; also elsewhere on the board

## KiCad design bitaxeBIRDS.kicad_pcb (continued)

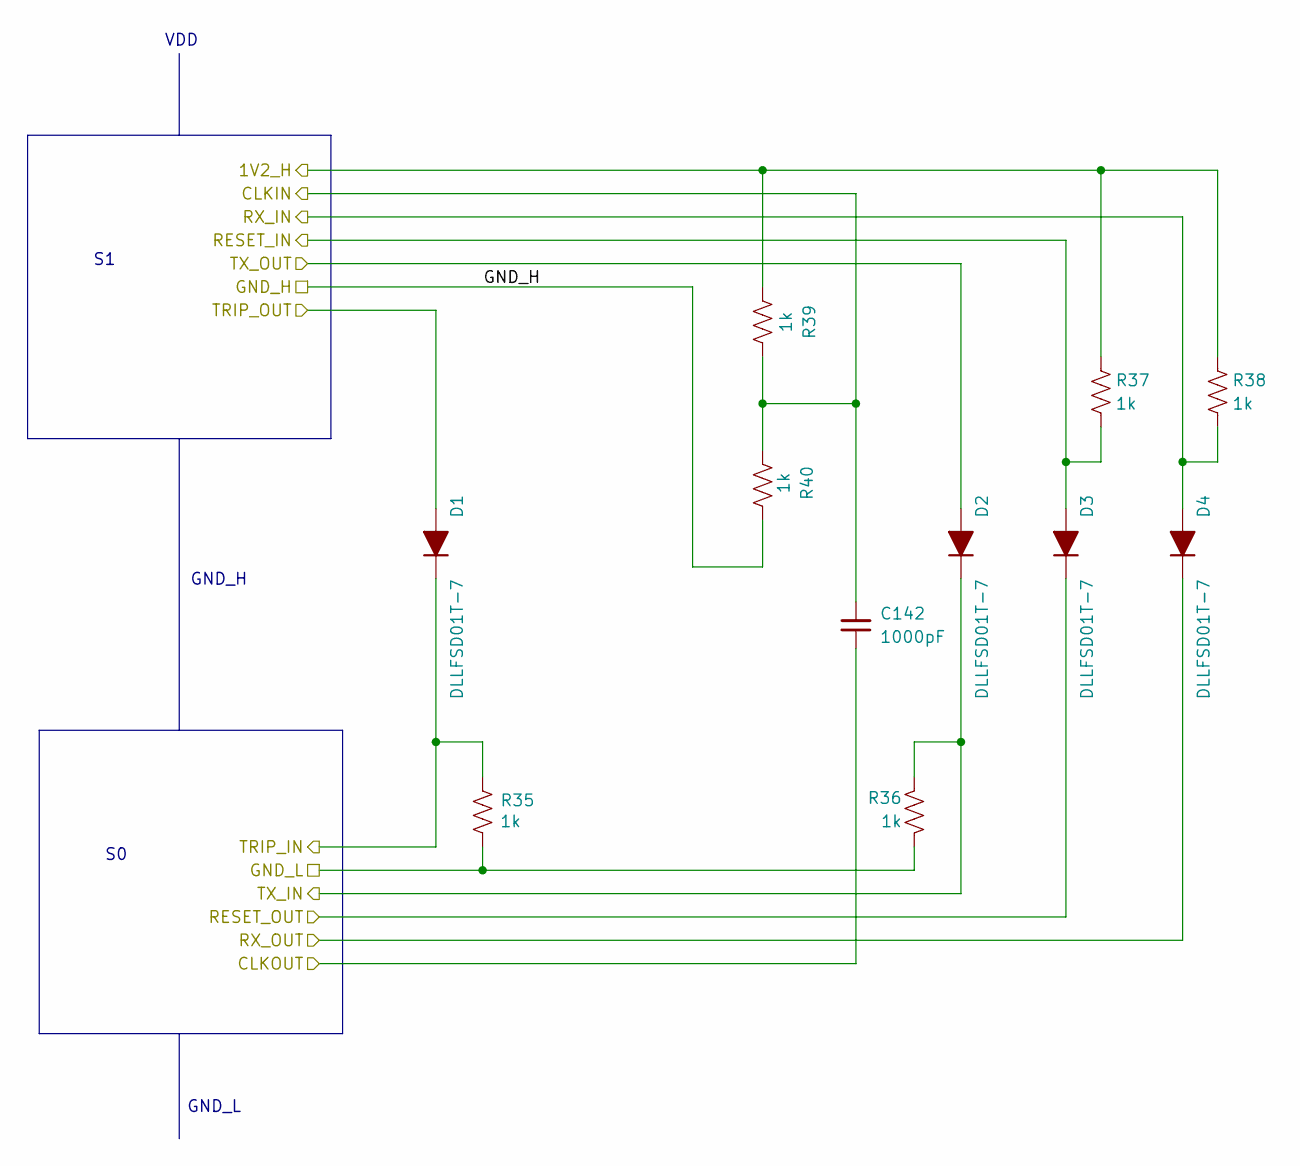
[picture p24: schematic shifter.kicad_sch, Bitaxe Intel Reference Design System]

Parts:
C142: 1000pF; C_0402_1005Metric; PARTNO GRM155R71H102KA01D
D1, D2, D3, D4: DLLFSD01T-7; D_SOD-523; PARTNO DLLFSD01T-7
R35, R36, R37, R38, R39, R40: 1k; R_0402_1005Metric; PARTNO RC0402FR-071KL

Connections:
/ASIC/1V2-2: R37.2, R38.1, R39.1; also elsewhere on the board
/ASIC/GND2: R40.2; also elsewhere on the board
/ASIC/REFCLKIN2: C142.2, R39.2, R40.1; also elsewhere on the board
/ASIC/REFCLKOUT1: C142.1; also elsewhere on the board
/ASIC/shifter1-2/RESET_IN: D3.A, R37.1; also elsewhere on the board
/ASIC/shifter1-2/RESET_OUT: D3.K; also elsewhere on the board
/ASIC/shifter1-2/RX_IN: D4.A, R38.2; also elsewhere on the board
/ASIC/shifter1-2/RX_OUT: D4.K; also elsewhere on the board
/ASIC/shifter1-2/TRIP_IN: D1.K, R35.1; also elsewhere on the board
/ASIC/shifter1-2/TRIP_OUT: D1.A; also elsewhere on the board
/ASIC/shifter1-2/TX_IN: D2.K, R36.1; also elsewhere on the board
/ASIC/shifter1-2/TX_OUT: D2.A; also elsewhere on the board
GND: R35.2, R36.2; also elsewhere on the board

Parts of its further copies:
C143, C144: 1000pF; C_0402_1005Metric; PARTNO GRM155R71H102KA01D
D5, D6, D7, D8, D9, D10, D11, D12: DLLFSD01T-7; D_SOD-523; PARTNO DLLFSD01T-7
R41, R42, R43, R44, R45, R46, R47, R48, R49, R50, R51, R52: 1k; R_0402_1005Metric; PARTNO RC0402FR-071KL

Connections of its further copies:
/ASIC/1V2-3: R43.2, R44.1, R45.1; also elsewhere on the board
/ASIC/1V2-4: R49.2, R50.1, R51.1; also elsewhere on the board
/ASIC/GND2: R41.2, R42.2; also elsewhere on the board
/ASIC/GND3: R46.2, R47.2, R48.2; also elsewhere on the board
/ASIC/GND4: R52.2; also elsewhere on the board
/ASIC/REFCLKIN3: C143.2, R45.2, R46.1; also elsewhere on the board
/ASIC/REFCLKIN4: C144.2, R51.2, R52.1; also elsewhere on the board
/ASIC/REFCLKOUT2: C143.1; also elsewhere on the board
/ASIC/REFCLKOUT3: C144.1; also elsewhere on the board
/ASIC/shifter2-3/RESET_IN: D7.A, R43.1; also elsewhere on the board
/ASIC/shifter2-3/RESET_OUT: D7.K; also elsewhere on the board
/ASIC/shifter2-3/RX_IN: D8.A, R44.2; also elsewhere on the board
/ASIC/shifter2-3/RX_OUT: D8.K; also elsewhere on the board
/ASIC/shifter2-3/TRIP_IN: D5.K, R41.1; also elsewhere on the board
/ASIC/shifter2-3/TRIP_OUT: D5.A; also elsewhere on the board
/ASIC/shifter2-3/TX_IN: D6.K, R42.1; also elsewhere on the board
/ASIC/shifter2-3/TX_OUT: D6.A; also elsewhere on the board
/ASIC/shifter3-4/RESET_IN: D11.A, R49.1; also elsewhere on the board
/ASIC/shifter3-4/RESET_OUT: D11.K; also elsewhere on the board
/ASIC/shifter3-4/RX_IN: D12.A, R50.2; also elsewhere on the board
/ASIC/shifter3-4/RX_OUT: D12.K; also elsewhere on the board
/ASIC/shifter3-4/TRIP_IN: D9.K, R47.1; also elsewhere on the board
/ASIC/shifter3-4/TRIP_OUT: D9.A; also elsewhere on the board
/ASIC/shifter3-4/TX_IN: D10.K, R48.1; also elsewhere on the board
/ASIC/shifter3-4/TX_OUT: D10.A; also elsewhere on the board

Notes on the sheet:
GND_H
VDD
GND_L

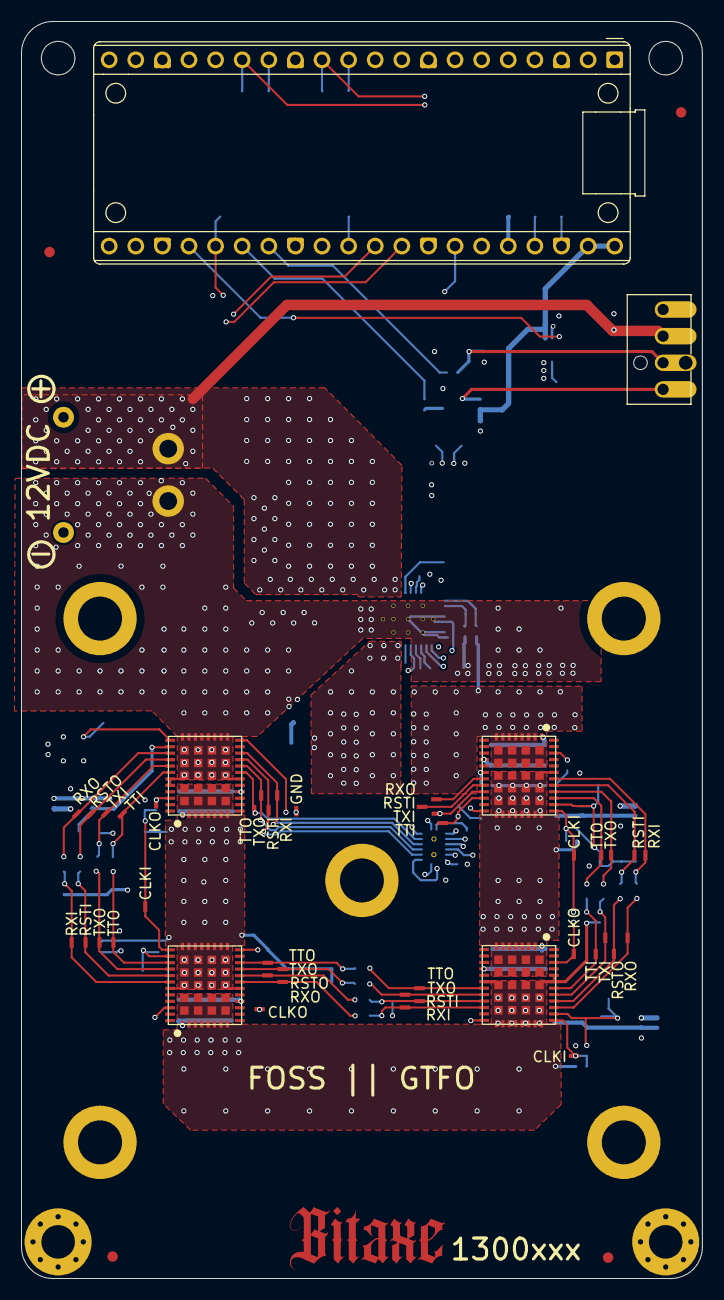
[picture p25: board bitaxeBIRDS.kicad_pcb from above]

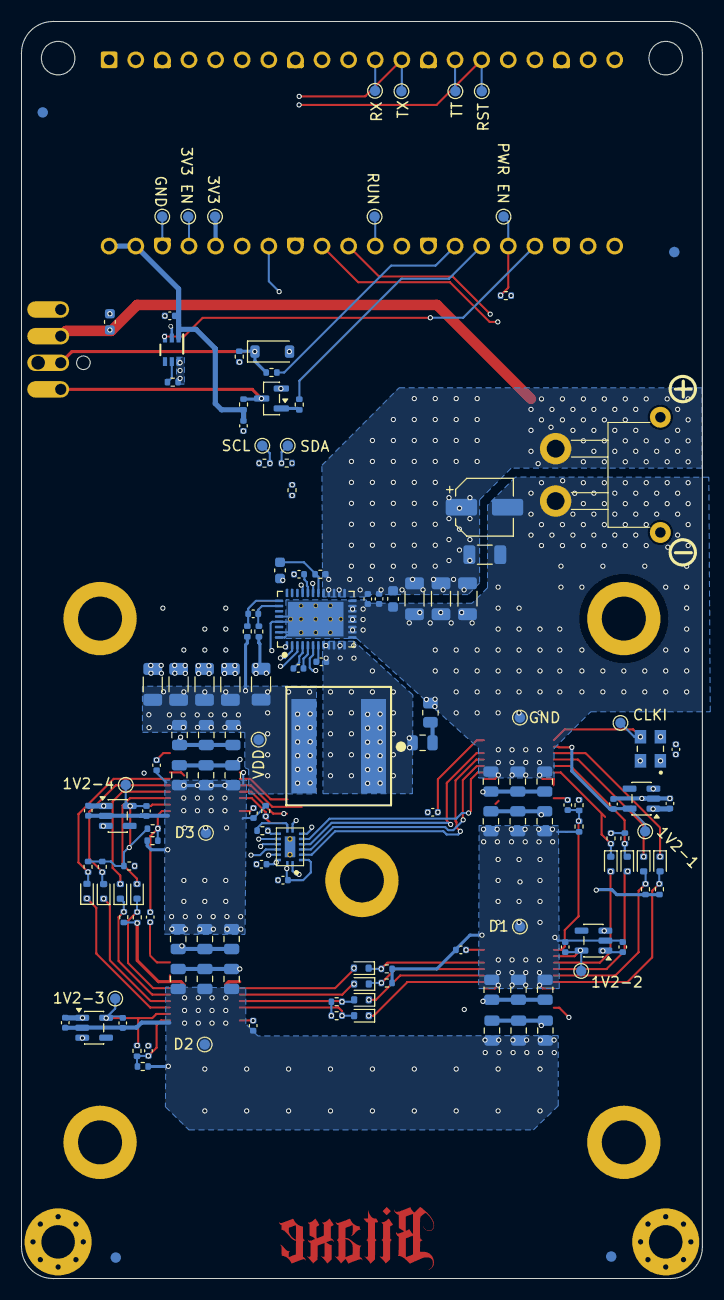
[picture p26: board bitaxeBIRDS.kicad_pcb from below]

Board: 6 copper layers, 65.0 x 120.0 mm, 199 parts (147 on the bottom side), 94 nets.

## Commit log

2025-10-02 created bitaxeBIRDS from bitaxeGT-800xxxx. moved over RP2040. initial import.
    [141_TL3330AFxxxQG.stp, 21-0164B_L622-1_MXM.step, 2R5TPE220MAFB.step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]
2025-10-02 started to piece in the BZM2 into schematic
    [ASIC.kicad_sch, bitaxeBIRDS.kicad_pcb, bitaxeBIRDS.kicad_sch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]
2025-10-02 finished adding ASICs to schematic. Change VR to single phase 2.8V output
    [ASIC.kicad_sch, BZM2.step, BZM2model.step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]
2025-10-03 switched to smaller level shifter diodes. switched ASIC modes
    [ASIC.kicad_sch, DIODE_DLLFSD01LPH4-7B_DIO.step, Power.kicad_sch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]
2025-10-03 switched to TINY LDOs.
    [ASIC.kicad_sch, DQN0004A.stp, bitaxeBIRDS.kicad_pcb]
2025-10-07 more routing
    [Power.kicad_sch, bitaxeBIRDS.kicad_pcb, data.kicad_sch]
2025-10-28 Added RP Pico W2 to schematic. Fixed Domain 1-2 level shifter pins. Added test points
    [ASIC.kicad_sch, Power.kicad_sch, RP-006426-DD-A-Raspberry Pi Pico 2 3D CAD Model R5 24 07 24.step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]
2025-10-28 switched to THT RPi Pico 2W style. Made 8mm taller.
    [ASIC.kicad_sch, Fan 60x60x25mm.stp, RaspberryPi_Pico_W_AddedHeaders.step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]
2025-10-29 lots of routing
    [ASIC.kicad_sch, bitaxeBIRDS.kicad_pcb, data.kicad_sch]
2025-10-29 routing done, needs DRC and cleanup
    [ASIC.kicad_sch, bitaxeBIRDS.kicad_pcb]
2025-10-30 Removed EMC2103, added discrete fan control, DRC pass, fixed logo.
    [DCK0006A.stp, ECS-3225MV-500-CN-TR.STEP, Power.kicad_sch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]
2025-10-30 power plane cleanup. added field vias. generated BOM
    [ASIC.kicad_sch, Power.kicad_sch, bitaxeBIRDS BOM.csv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]
2025-10-30 update TPS546D24 to `S` variant. Add render and readme.
    [ASIC.kicad_sch, Power.kicad_sch, bitaxeBIRDS BOM.csv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]
2025-11-06 Correct U8 value field.
    [bitaxeBIRDS BOM.csv, data.kicad_sch]
2025-11-06 unify 1k resistor part numbers
    [ASIC.kicad_sch, bitaxeBIRDS BOM.csv, shifter.kicad_sch]
2025-11-06 update C9 and C10 to the correct 0603 footprint. Change C15 part number to be 0402
    [Power.kicad_sch, bitaxeBIRDS.kicad_pcb]
2025-11-06 update 50MHz osc part number.
    [ASIC.kicad_sch]
2025-11-06 change Y2 OSC part number back.
    [ASIC.kicad_sch]
2025-11-24 Add firmware support details and clarify Gerber policy
    Updated README to include preliminary support for bitaxe-raw-pico firmware and clarified Gerber availability.
2025-11-30 TX_IN modified to pull low to GND_L in level shifter (Closes: #2)
    [shifter.kicad_sch]
2025-11-30 Added footprint library configuration so KiCad can find bitaxe.pretty
    Also, we can ignore generated files for the BOM
2025-11-30 Rerouoted the traces for the pull-down resistor on TX_IN for each level
    [bitaxeBIRDS.kicad_pcb]
2026-02-09 add inductor footprint
    [Power.kicad_sch, bitaxeBIRDS.kicad_pcb]
2026-02-09 clean up some of the schematic errors for #4
    [ASIC.kicad_sch, bitaxeBIRDS.kicad_pcb, bitaxeBIRDS.kicad_sch]
2026-02-09 cleaned up lots of ERC errors and warnings for #4
    [ASIC.kicad_sch, Power.kicad_sch, bitaxeBIRDS.kicad_pcb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]
2026-02-10 fix part numbers for C60-C64 for #5
    [ASIC.kicad_sch, bitaxeBIRDS.kicad_pcb, bitaxeBIRDS.kicad_sch]
2026-02-10 added pull resistors for #1
    [ASIC.kicad_sch, bitaxeBIRDS.kicad_pcb, bitaxeBIRDS.kicad_sch]
2026-02-10 changed all the level shifting diodes to SOD-523 packages for #6
    [ASIC.kicad_sch, Power.kicad_sch, bitaxeBIRDS.kicad_pcb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]
2026-02-10 change IO voltage LDOs to bigger packages for #6
    [ASIC.kicad_sch, bitaxeBIRDS.kicad_pcb]
2026-02-15 fix pinsel connection on ASIC 3 for #7
    [ASIC.kicad_sch, bitaxeBIRDS.kicad_pcb]

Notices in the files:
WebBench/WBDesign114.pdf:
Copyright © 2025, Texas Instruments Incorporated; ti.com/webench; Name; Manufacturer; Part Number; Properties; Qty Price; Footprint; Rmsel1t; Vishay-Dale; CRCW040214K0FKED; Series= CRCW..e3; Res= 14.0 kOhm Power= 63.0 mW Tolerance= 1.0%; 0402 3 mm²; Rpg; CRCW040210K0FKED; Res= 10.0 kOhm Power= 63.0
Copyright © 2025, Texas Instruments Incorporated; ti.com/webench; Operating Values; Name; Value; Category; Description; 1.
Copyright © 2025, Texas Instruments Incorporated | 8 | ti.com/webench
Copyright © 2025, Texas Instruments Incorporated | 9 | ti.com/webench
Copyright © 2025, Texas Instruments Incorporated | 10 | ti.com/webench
